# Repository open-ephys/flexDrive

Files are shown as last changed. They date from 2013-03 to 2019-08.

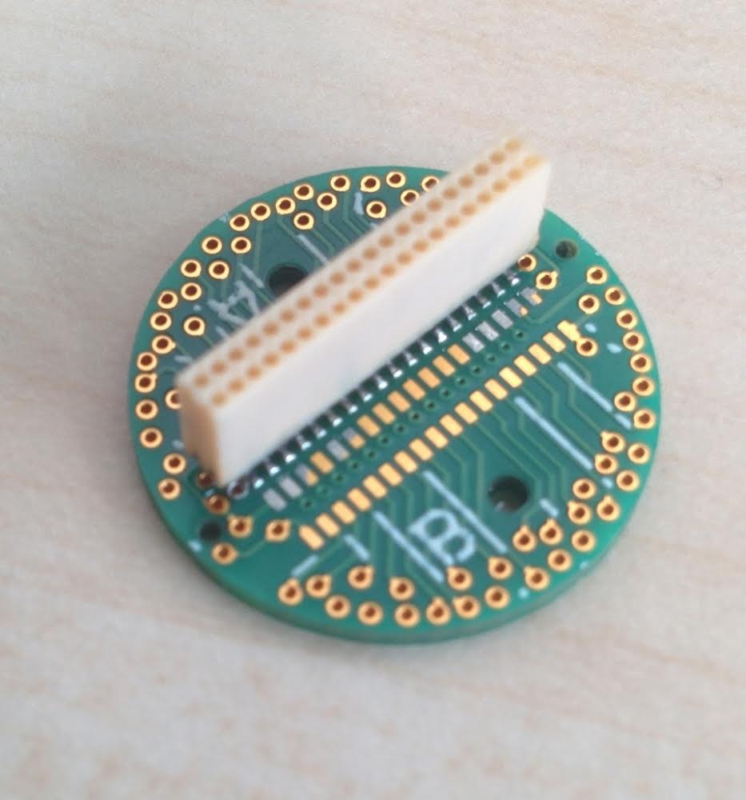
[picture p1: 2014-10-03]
Electrode Interface Boards/Omnetics 2x32/aligned connectors/doc/2x32aligned_eib_half_soldered.jpg

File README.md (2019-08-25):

flexDrive
==========

__This design is deprecated, we recommend switching to the newer Open Ephys shuttle drive__ (preprint: https://www.biorxiv.org/content/10.1101/746651v1), (git repository: https://github.com/open-ephys/shuttle-drive). This new design is superior to the flexDrive in all aspects (robustness, travel distance, build speed), and we strongly recommend switching.

The flexDrive is a compact hyperdrive for up to 16 independently movable electrodes. It uses a novel spring mechanism to adjust electrode depth.

This repository only contains design files. See https://open-ephys.atlassian.net/wiki/display/OEW/flexDrive for documentation and assembly instructions.

File types
------------
- .brd = EAGLE board files; describe the physical layout of the printed circuit board
- .md = Markdown files; most likely a README file; can be viewed with any text edtior
- .txt  = standard text files
- "gerber" files (.top, .bsk, .oln, etc.) = contain machine-readable instructions for creating the printed circuit board; these are sent to a fab house (such as Sunstone Circuits) for PCB production
- .SLDPRT files = SolidWorks part files; contain CAD models of 3D components
- .SLDDRW files = SolidWorks drawing files; contain 2D images of components
- .DXF = another type of 2D drawing file that can be opened in Adobe Illustrator or similar software
- .STL files = stereolithography files; can be sent to a rapid prototyping service (such as Shapeways) to create 3D objects
- .pdf files = standard document format for viewing and editing 2D images

Paper
----------

Voigts J, Siegle JH, Pritchett DL and Moore CI (2013). 
The flexDrive: An ultra-light implant for optical control and highly parallel chronic recording of neuronal ensembles in freely moving mice. 
Front. Syst. Neurosci. 7:8. doi: 10.3389/fnsys.2013.00008

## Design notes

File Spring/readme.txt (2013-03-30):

The flexDrive is an implant for chronic extracellular electrophysiology.
The design of the flexDrive is released under the The TAPR Open Hardware License
Get the latest revision of the design source files at http://github.com/open-ephys/flexDrive

The spring design files in this repository are designed for use with wire EDM with a kerf width of 13mil, using any other process requires adapting at least the screw opening in the spring. 

Editing the sldprt of DXF files requires Dassault Systems Solidworks (http://www.solidworks.com/)

Voigts J, Siegle JH, Pritchett DL and Moore CI (2013). 
The flexDrive: An ultra-light implant for optical control and highly parallel chronic recording of neuronal ensembles in freely moving mice. 
Front. Syst. Neurosci. 7:8. doi: 10.3389/fnsys.2013.00008

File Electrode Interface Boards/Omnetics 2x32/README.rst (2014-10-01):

2x Omnetics 36-channel "nano-strip" connectors, 4 guide posts
---------------------------------------------------------------------------------

The 64ch_eib_omnetics_3fibers Electrode Interface Board  (EIB) is designed to form a connection between 64 microwire electrodes or individual wires forming stereotrodes or tetrodes, and two 32 channel omnetics connectors.

The 'offset variant' provides more space between the two omnetics connectors and can be soldered by hand if needed, but won't fit the 64 channel headstage.

The aligned variant fits the 64 channel headstage, and can also be used with 2x 32 channel headstages, if they're aligned with the PCB facing away from the center (this will affect the channel mapping).

See the documentation on https://open-ephys.atlassian.net/wiki/display/OEW/flexDrive for building and use instructions.

**WARNING:** These designs will not work if fabricated as 'standard quality' PCB, see Fabrication instructions and get in touch with your PCB maker before placing orders!

Connectors on EIB:
~~~~~~~~~~~~~~~

* male surface-mount vertical (A79026-001 / NPD-36-VV-GS)

Connectors on Headstage:
~~~~~~~~~~~~~~~~~~
 
* female surface-mount horizontal (A79025-001 / NSD-36-AA-GS)
* female surface-mount vertical (A79027-001 / NSD-36-VV-GS)

Pin mapping:
~~~~~~~~~~~~~~~~~~
The pin mapping for the GROUND and REFERENCE channels on the offset connector EIB are compatible with the mapping on the Intan evaluation system headstages (http://www.intantech.com/files/Intan_RHD2000_eval_system.pdf) and the open-ephys headstages (open-ephys.org)

(viewed down onto the eib, looking onto the bottom of the headstage connector this would be flipped)

| ref  | ch | ch | ... | ch | gnd |
| gnd | ch | ch | ... | ch | ref |

For channel mappings of individual EIB designs, look at the documenttaiopn in that EIBs folder. Orientation of headstages affects the channel mapping - when in doubt you should sanity check your mapping by connecting a EIB to your system and grounding out or injecting a signal on individual vias.

Hole sizes:
~~~~~~~~~~~~~~~~~~

The hole size on this EIB (0.3mm) is suited for use with SMALL neuralynx gold pins (http://neuralynx.com/products/electrode_interface_boards/eib_pins) 

The three mounting holes for optical fiber ferrules are sized for use with 1.25mm OD ferrules.

See the documentation on https://open-ephys.atlassian.net/wiki/display/OEW/flexDrive for building and use instructions.

Fabrication instructions:
~~~~~~~~~~~~~~~~~~

These EIBs can be fabricated with the following process
- 5mil trace with / 5mil trace space
- gold immersion finish
- 0.03 inch board thickness (not critical, can be made thicker)
- top silkscreen

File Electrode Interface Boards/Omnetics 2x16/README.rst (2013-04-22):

Omnetics 18-channel "nano-strip" connectors, 4 guide posts
---------------------------------------------------------------------------------

The 32ch_eib_omnetics_2fibers and 32ch_eib_omnetics_1fiber Electrode Interface Boards (EIB) aredesigned to form a connection between 32microwire electrodes or individual wires forming stereotrodes or tetrodes, and two 16 channel omnetics connectors.

See the documentation on http://github.com/open-ephys/flexDrive for building and use instructions.

Connectors on EIB:
~~~~~~~~~~~~~~~

* male surface-mount vertical (A79042-001 / NPD-18-VV-GS)

Connectors on Headstage:
~~~~~~~~~~~~~~~~~~
 
* female surface mount horizontal (A79041-001 / NSD-18-AA-GS)
* female surface mount vertical (A79043-001 / NSD-18-VV-GS)

Pin mapping:
~~~~~~~~~~~~~~~~~~
The pin mapping for the GROUND and REFERENCE channels on this EIB are compatible with the mapping on the standard omnetics 16 channel headstages.

Hole sizes:
~~~~~~~~~~~~~~~~~~
The hole size on this EIB (0.5mm) is suited for use with LARGE neuralynx gold pins (http://neuralynx.com/products/electrode_interface_boards/eib_pins) 

The mounting holes for optical fiber ferrules are sized for use with 1.25mm OD ferrules.

Fabrication instructions:
~~~~~~~~~~~~~~~~~~

This EIB can be fabricated with the following process
- 8mil trace with / 8mil trace space
- 0.03 inch board thickness (not critical, can be made thicker)
- top silkscreen

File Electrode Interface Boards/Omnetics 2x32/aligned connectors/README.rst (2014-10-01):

2x Omnetics 36-channel "nano-strip" connectors, 4 guide posts
---------------------------------------------------------------------------------

Fabrication instructions:
~~~~~~~~~~~~~~~~~~

check if these are correct:

These EIBs can be fabricated with the following process
- 5mil trace with / 5mil trace space
- gold immersion finish
- 0.03 inch board thickness (not critical, can be made thicker)
- top silkscreen

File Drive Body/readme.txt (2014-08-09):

The flexDrive is an implant for chronic extracellular electrophysiology.
The design of the flexDrive is released under the The TAPR Open Hardware License
Get the latest revision of the design source files at http://github.com/open-ephys/flexDrive

folder for_small_eibs holds the standard design that works with the 32ch eib and 64ch eib (small gold pins)

folder for_larger_64ch_eib contains a variant for use with the bigger 64ch eib (large gold pins)

Editing the sldprt files requires Dassault Systems Solidworks (http://www.solidworks.com/)

We also provide a STL file for use with 3d-printing software or services.

See (http://open-ephys.github.io/flexDrive/custom_parts.html) for ordering info.

Voigts J, Siegle JH, Pritchett DL and Moore CI (2013). 
The flexDrive: An ultra-light implant for optical control and highly parallel chronic recording of neuronal ensembles in freely moving mice. 
Front. Syst. Neurosci. 7:8. doi: 10.3389/fnsys.2013.00008

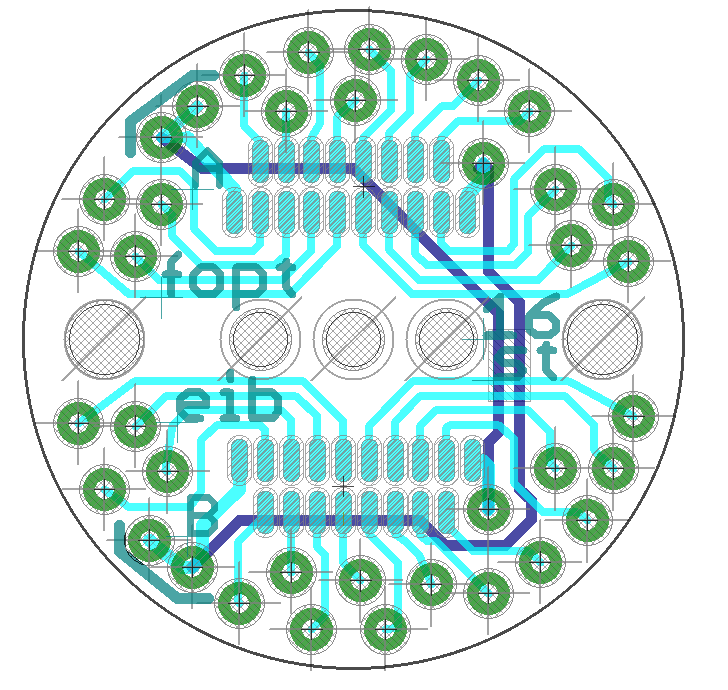
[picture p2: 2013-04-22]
Electrode Interface Boards/Omnetics 2x16/3 fiber optics/Open Ephys EIB Omnetics 2x16 3 fibers.png

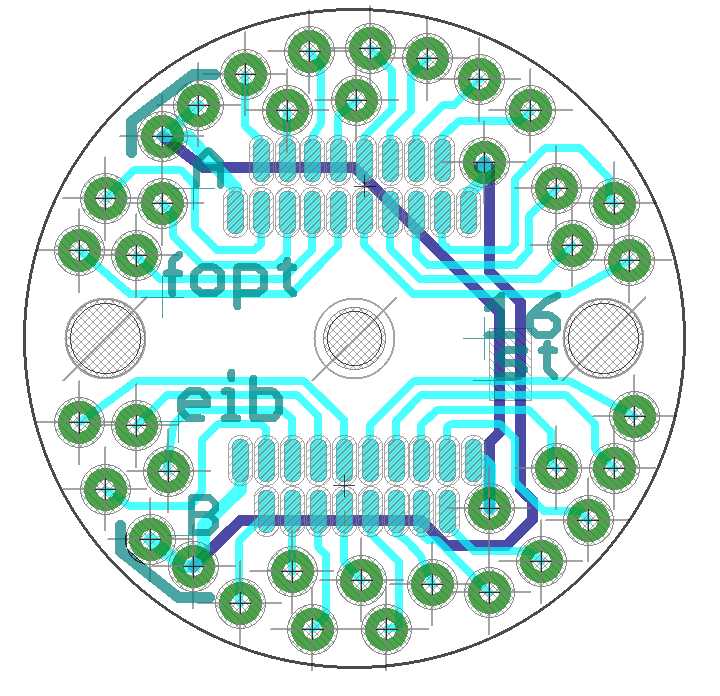
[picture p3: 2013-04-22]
Electrode Interface Boards/Omnetics 2x16/1 fiber optic/Open Ephys EIB Omnetics 2x16 1 fiber.png

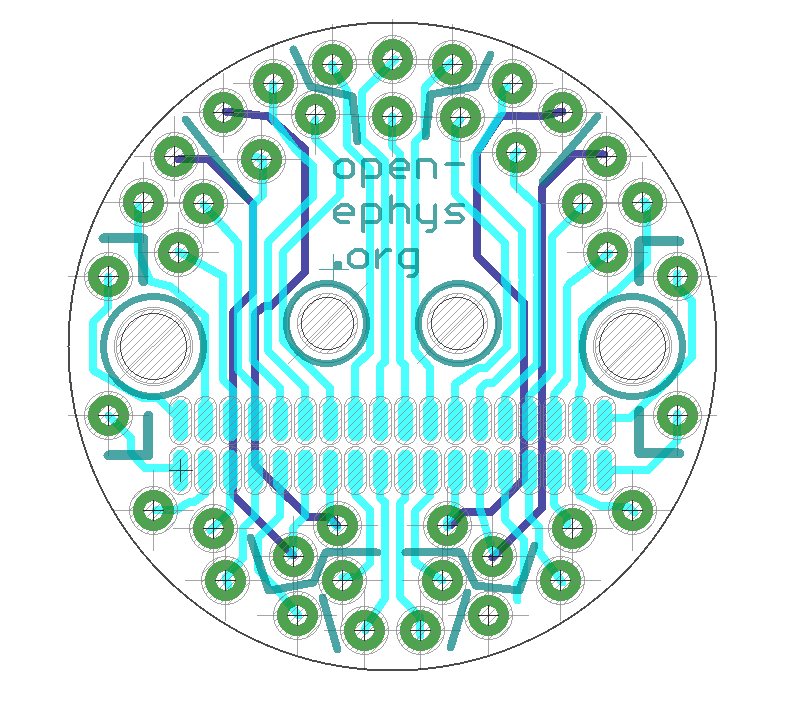
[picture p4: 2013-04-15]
Electrode Interface Boards/Omnetics 1x32/2 fibers/Open Ephys EIB Omnetics 1x32 2 fibers.png

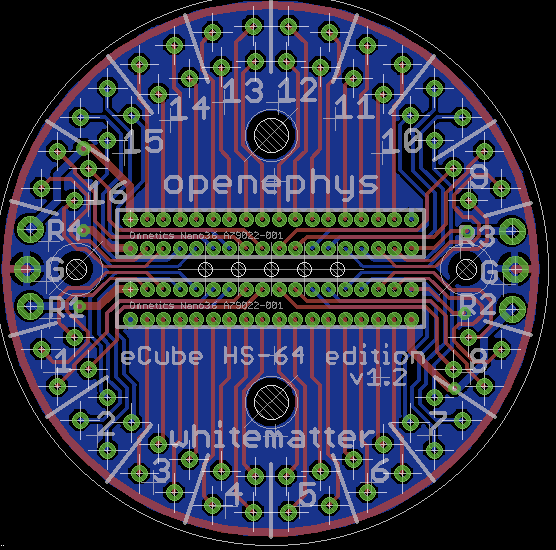
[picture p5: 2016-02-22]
Electrode Interface Boards/eCube HS-64/ecube EIB HS64 2xOmnetics r1 0.30mm.tiff

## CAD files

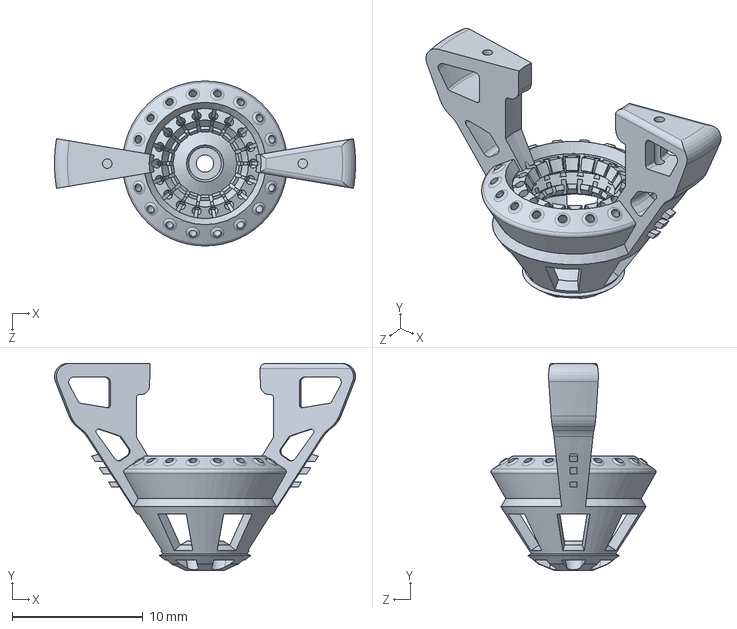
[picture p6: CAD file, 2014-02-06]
Drive Body/for_larger_64ch_eib/flexDrive_single_hole_16drives_rev1.2.SLDPRT
23.1 x 15.9 x 12.6 mm

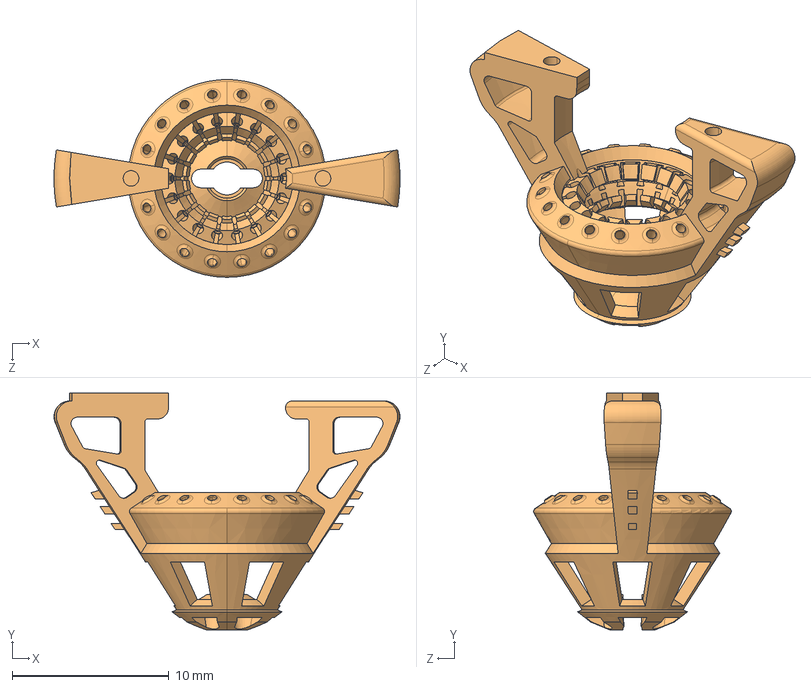
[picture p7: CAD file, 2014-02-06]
Drive Body/for_small_eibs/flexDrive_base_16drives_rev1.1.STEP
22.1 x 15.1 x 12.6 mm

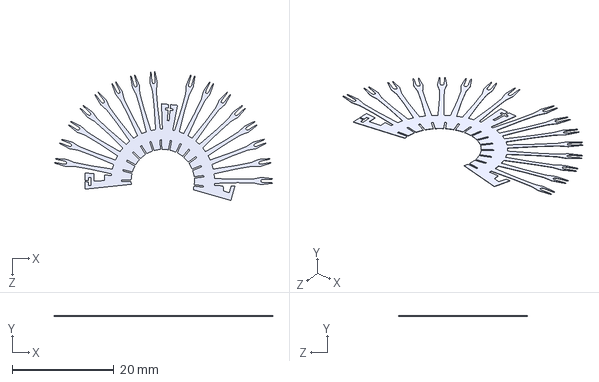
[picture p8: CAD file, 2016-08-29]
Spring/flexDrive_spring_16drives_rev1.2_nokerf.STEP
42.8 x 0.05 x 25.3 mm

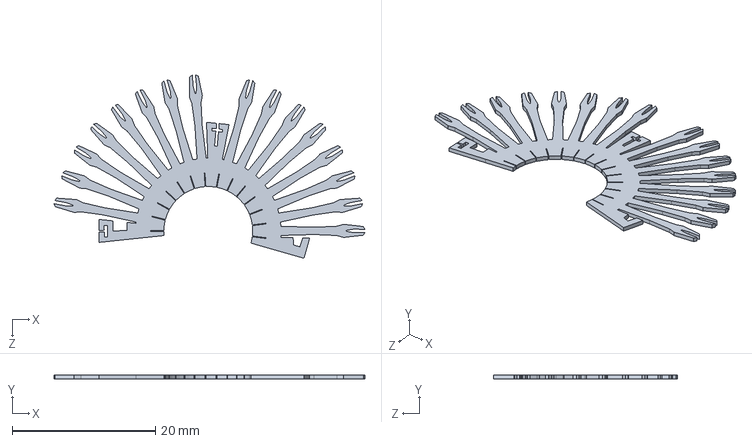
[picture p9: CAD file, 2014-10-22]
Spring/flexDrive_spring_16drives_rev1.2_for_13mil_kerf.SLDPRT
43.4 x 0.5 x 25.6 mm

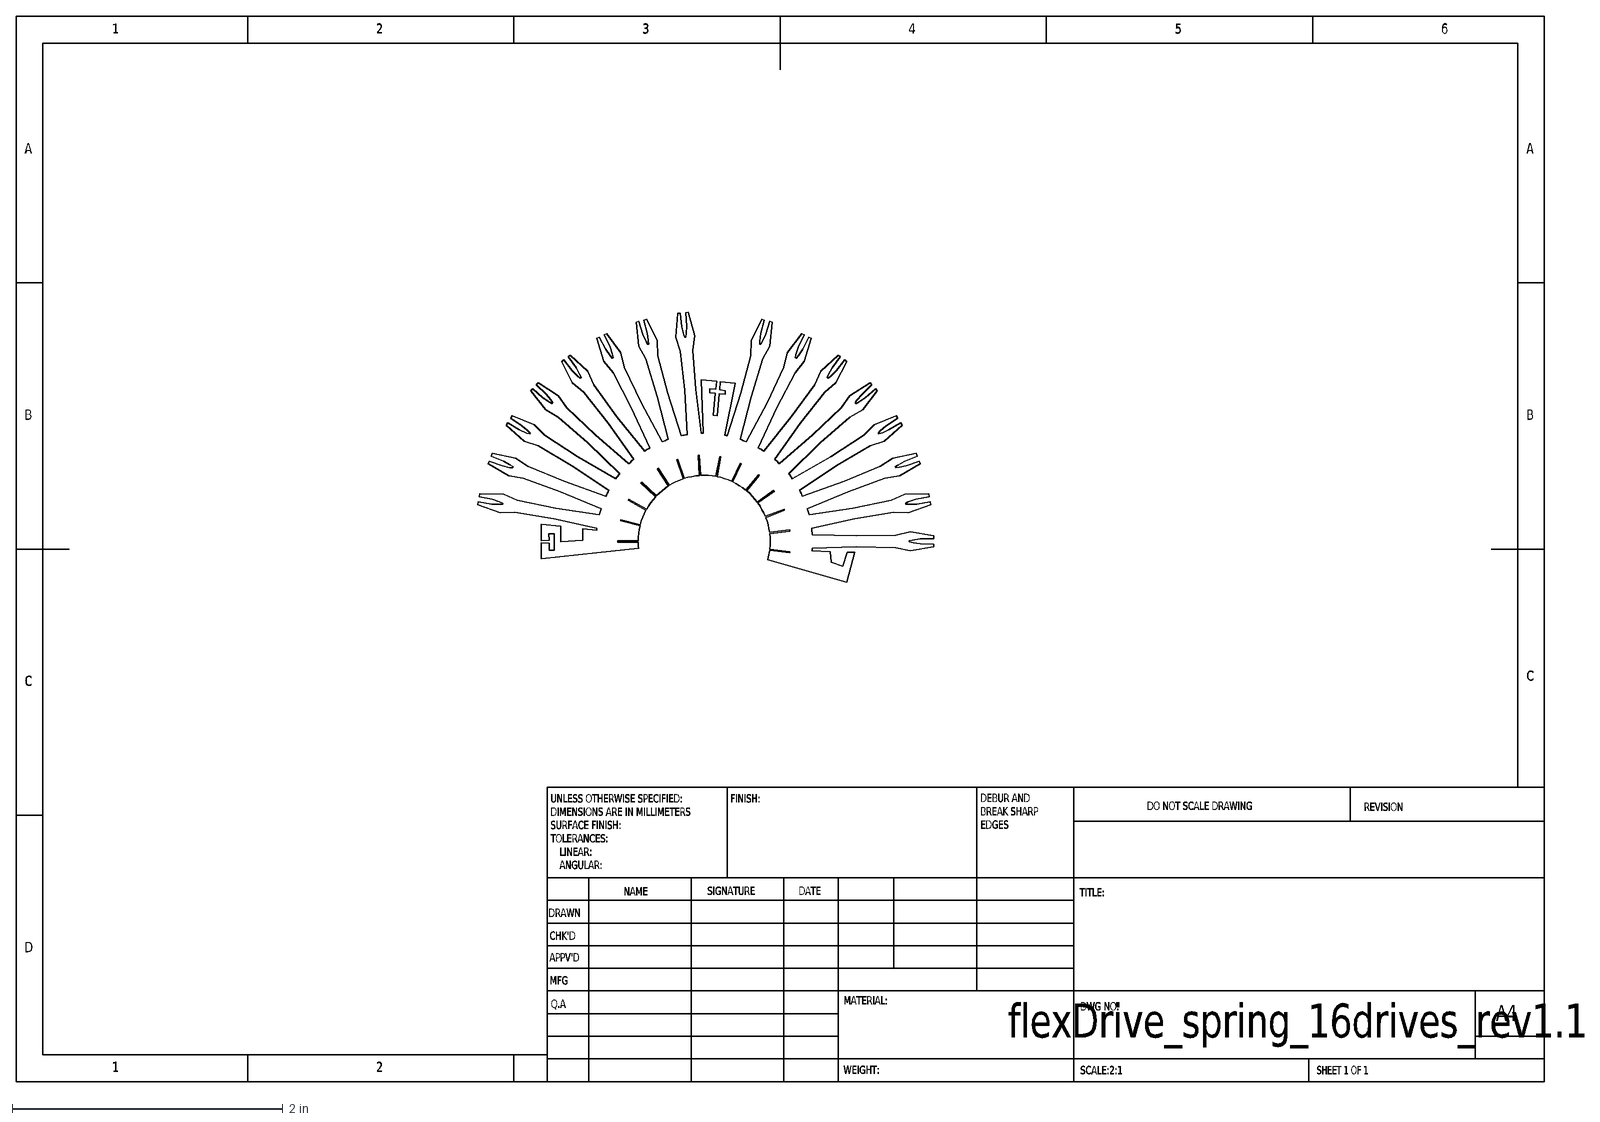
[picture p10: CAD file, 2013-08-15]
Spring/flexDrive_spring_16drives_rev1.1_wireedm_dfx_inch.DXF
B
C
D
1
2
A
3
4
5
6
DRAWN
CHK'D
APPV'D
MFG
Q.A
UNLESS OTHERWISE SPECIFIED:
DIMENSIONS ARE IN MILLIMETERS
SURFACE FINISH:
TOLERANCES:
LINEAR:
ANGULAR:
FINISH:
DEBUR AND
BREAK SHARP
EDGES
NAME
SIGNATURE
DATE
MATERIAL:
DO NOT SCALE DRAWING
REVISION
TITLE:
DWG NO.
SCALE:2:1
SHEET 1 OF 1
A4
WEIGHT:
flexDrive_spring_16drives_rev1.1

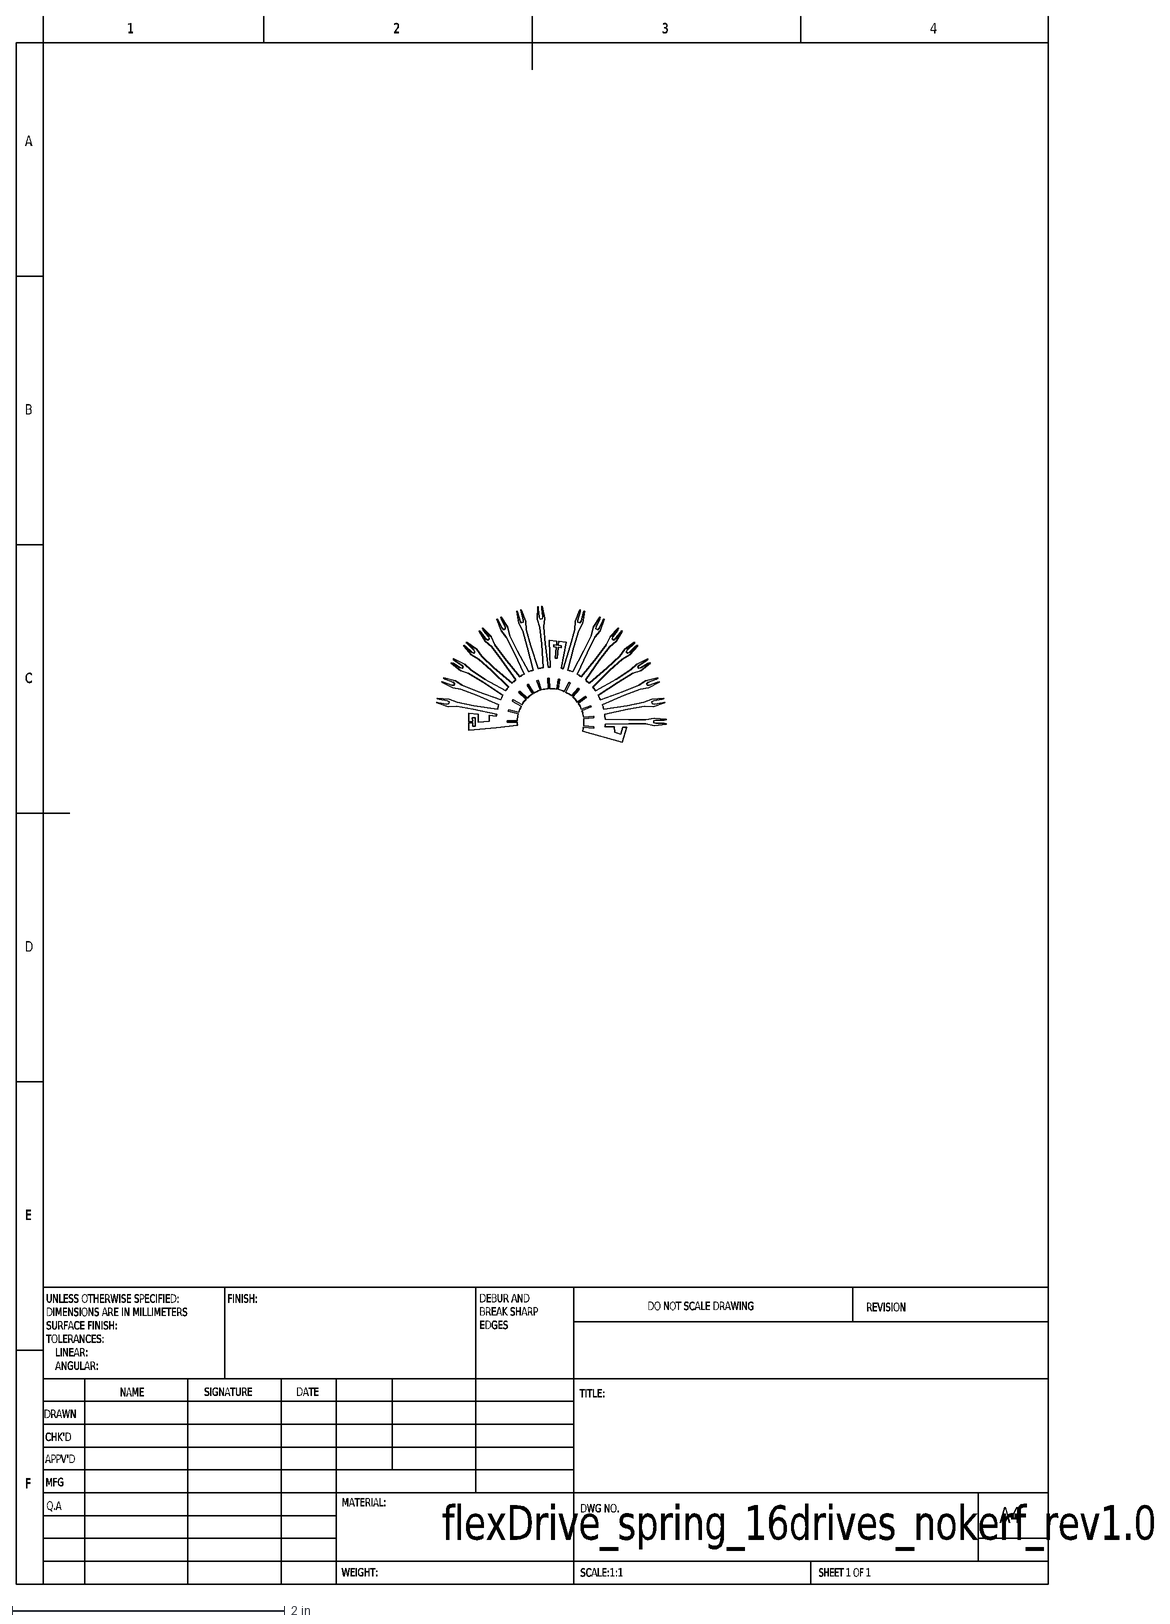
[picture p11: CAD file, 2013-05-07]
Spring/flexDrive_spring_16drives_nokerf_rev1.0_wireedm_dfx_inch.DXF
C
2
3
1
4
B
A
D
E
F
flexDrive_spring_16drives_nokerf_rev1.0
WEIGHT:
A4
SHEET 1 OF 1
SCALE:1:1
DWG NO.
TITLE:
REVISION
DO NOT SCALE DRAWING
MATERIAL:
DATE
SIGNATURE
NAME
DEBUR AND
BREAK SHARP
EDGES
FINISH:
UNLESS OTHERWISE SPECIFIED:
DIMENSIONS ARE IN MILLIMETERS
SURFACE FINISH:
TOLERANCES:
LINEAR:
ANGULAR:
Q.A
MFG
APPV'D
CHK'D
DRAWN

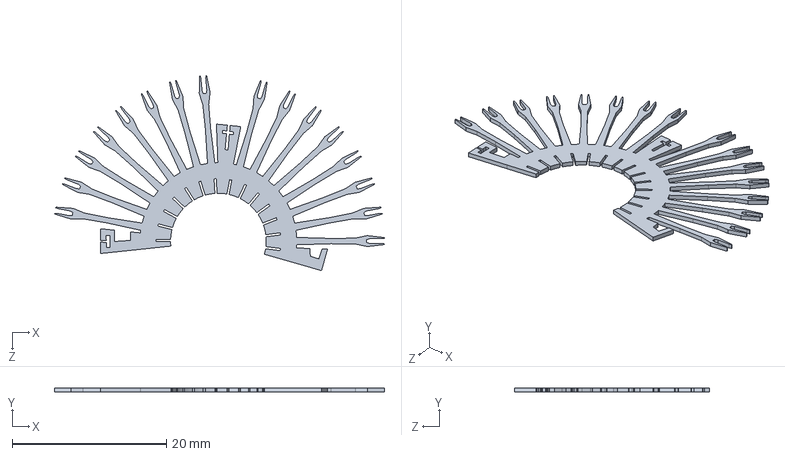
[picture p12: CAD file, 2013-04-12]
Spring/flexDrive_spring_16drives_nokerf_rev1.0.SLDPRT
42.8 x 0.5 x 25.3 mm

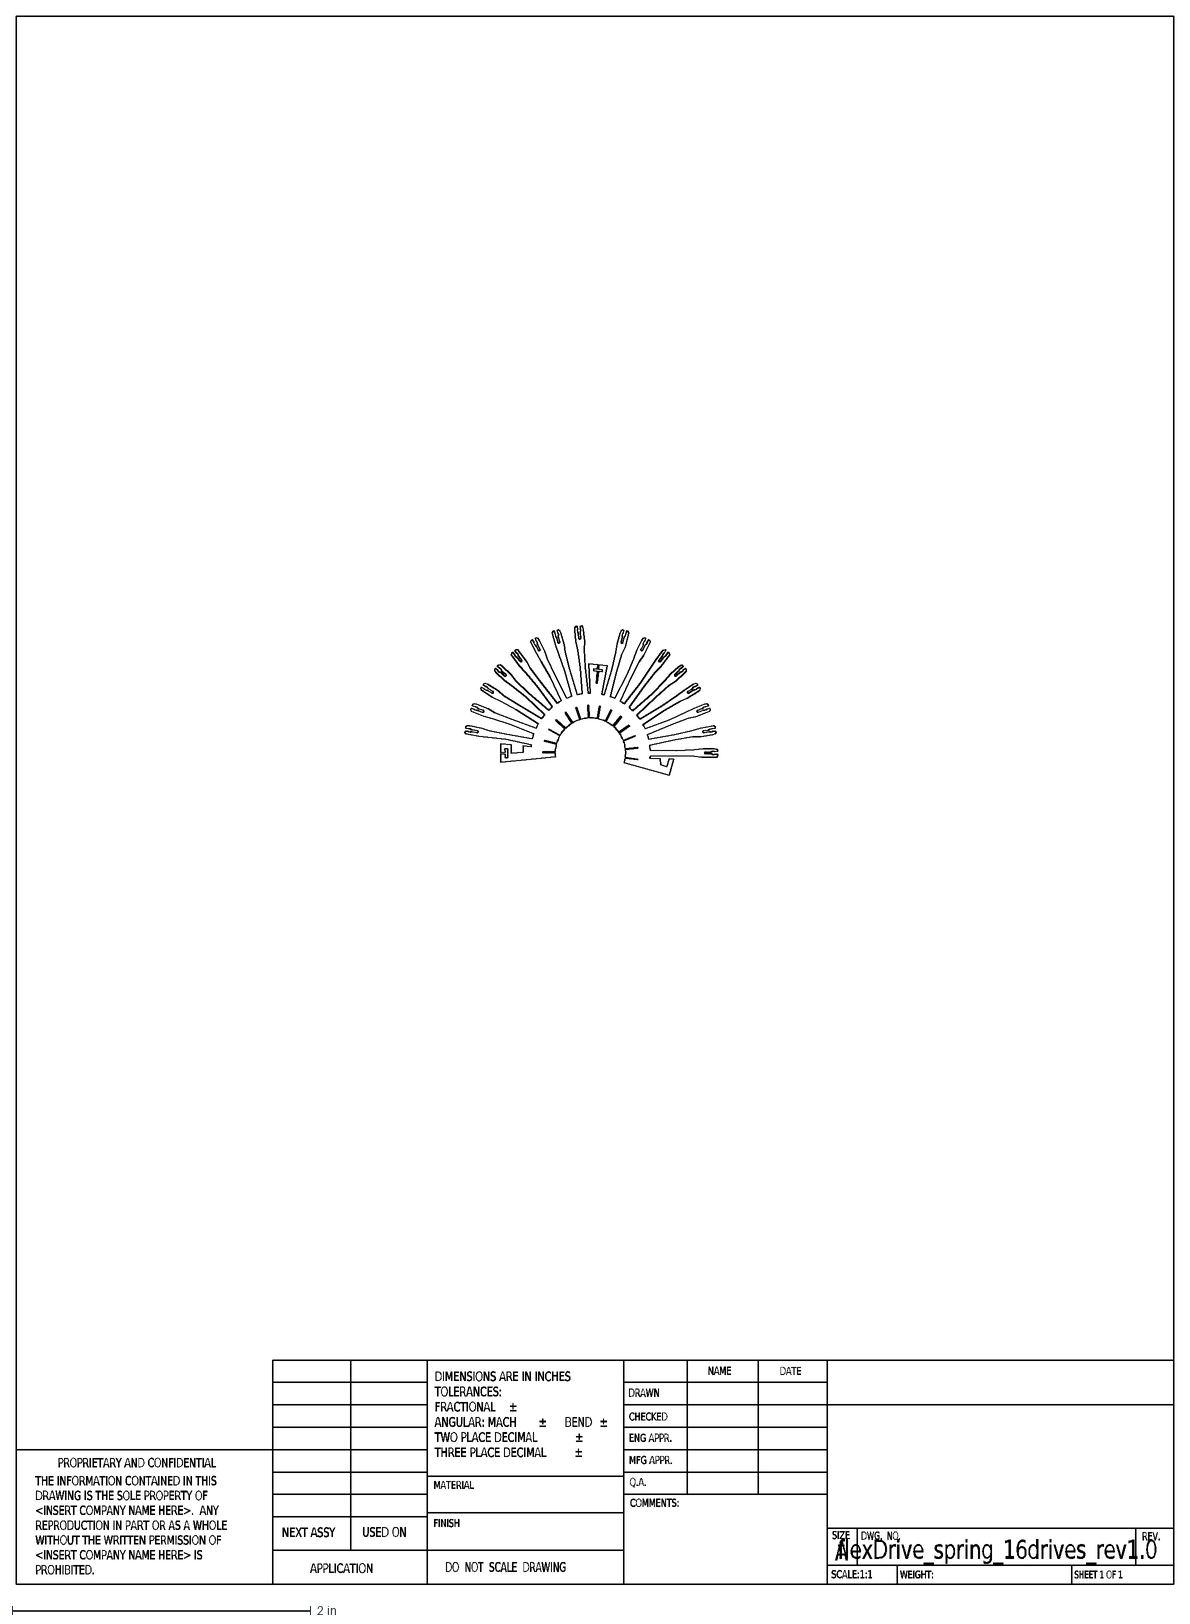
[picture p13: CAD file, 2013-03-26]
Spring/flexDrive_spring_16drives_rev1.0_wireedm_dfx_mm.DXF
WEIGHT:
flexDrive_spring_16drives_rev1.0
PROPRIETARY AND CONFIDENTIAL
THE INFORMATION CONTAINED IN THIS
DRAWING IS THE SOLE PROPERTY OF
<INSERT COMPANY NAME HERE>. ANY
REPRODUCTION IN PART OR AS A WHOLE
WITHOUT THE WRITTEN PERMISSION OF
<INSERT COMPANY NAME HERE> IS
PROHIBITED.
COMMENTS:
SHEET 1 OF 1
Q.A.
MFG APPR.
ENG APPR.
CHECKED
DRAWN
DATE
NAME
DIMENSIONS ARE IN INCHES
TOLERANCES:
FRACTIONAL
±
ANGULAR: MACH
BEND
TWO PLACE DECIMAL
THREE PLACE DECIMAL
NEXT ASSY
USED ON
APPLICATION
DO NOT SCALE DRAWING
FINISH
MATERIAL
REV.
A
DWG. NO.
SIZE
SCALE:1:1

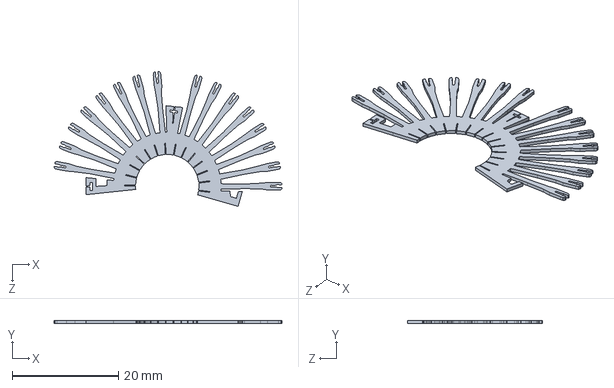
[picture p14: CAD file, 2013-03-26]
Spring/flexDrive_spring_16drives_rev1.0.SLDPRT
43.0 x 0.5 x 25.4 mm

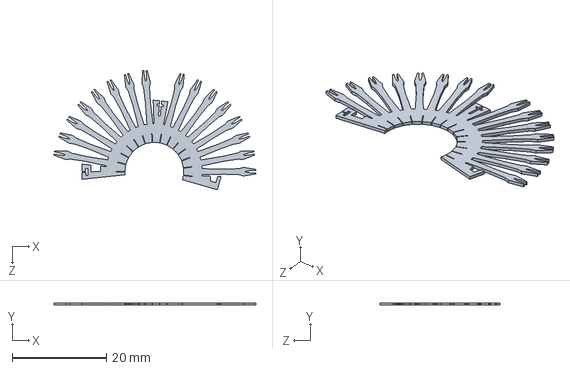
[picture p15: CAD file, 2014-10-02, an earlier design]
Spring/flexDrive_spring_16drives_rev1.1_for_13mil_kerf.SLDPRT
42.8 x 0.5 x 25.3 mm

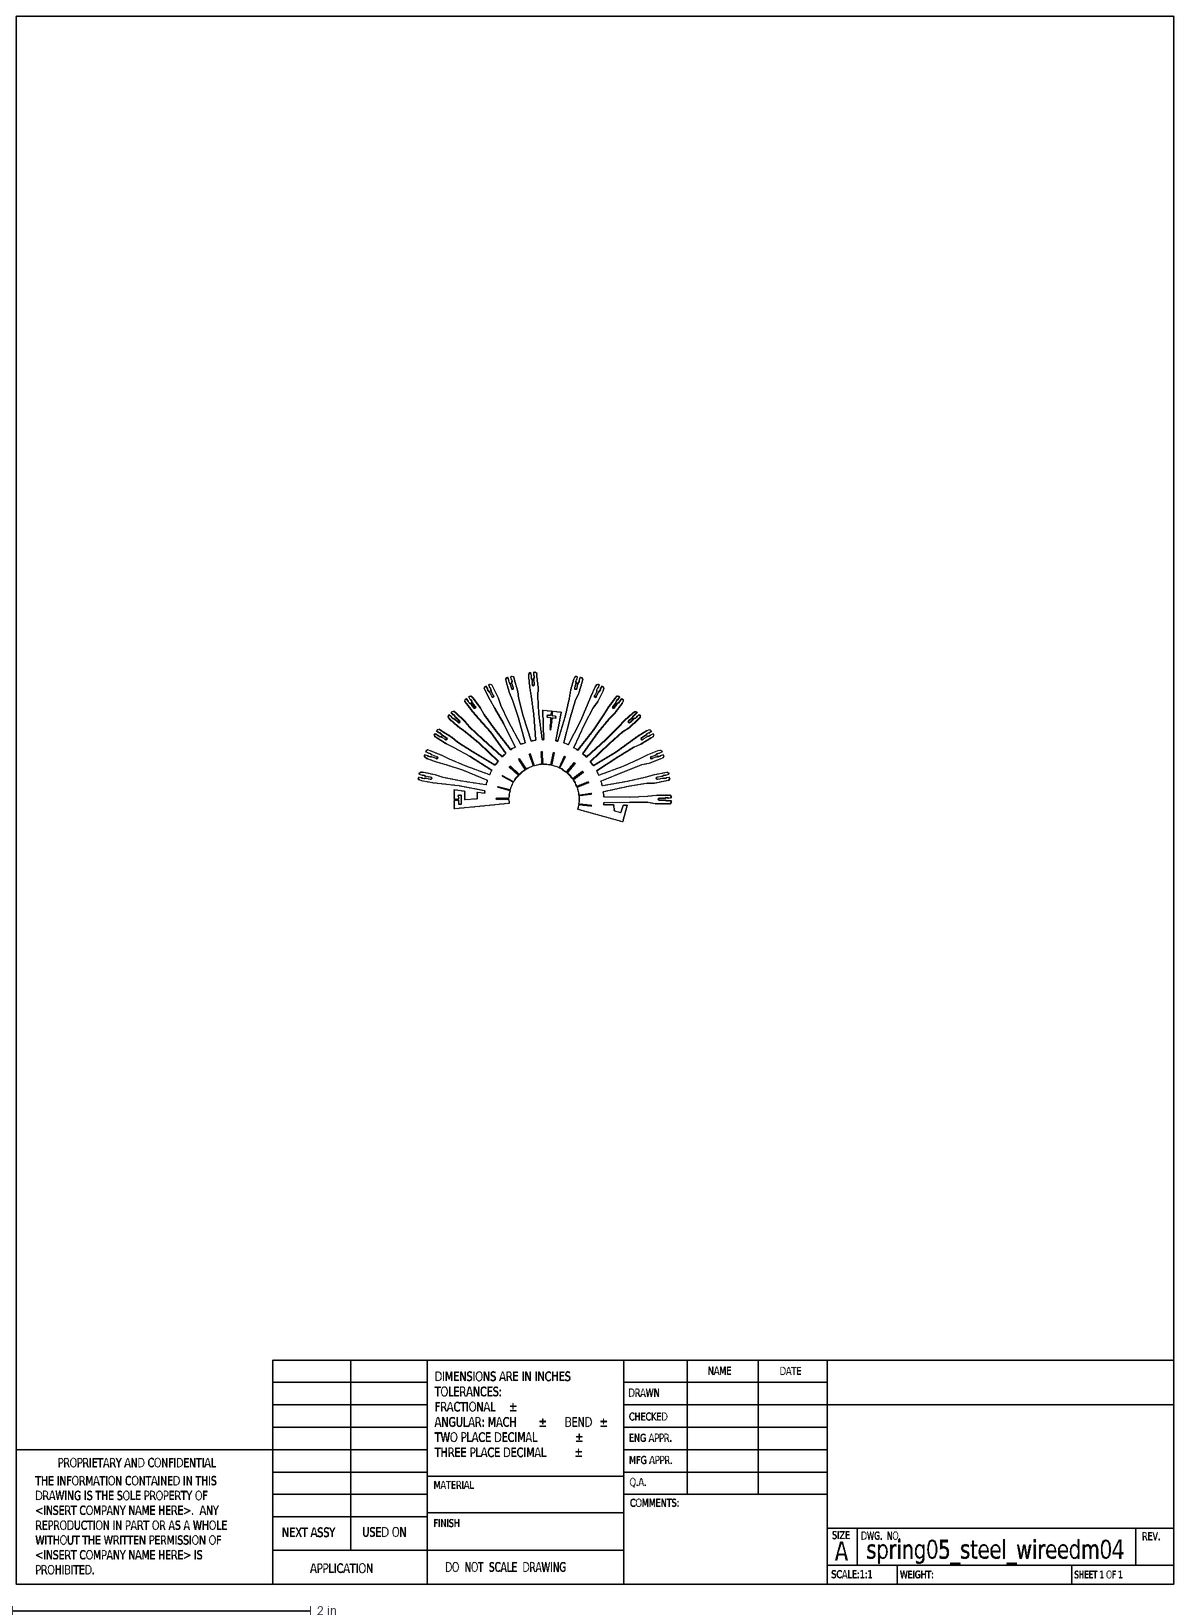
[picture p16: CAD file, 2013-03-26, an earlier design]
Spring/flexDrive_spring_16drives_rev1.0_wireedm_dfx_inch.DXF
WEIGHT:
spring05_steel_wireedm04
PROPRIETARY AND CONFIDENTIAL
THE INFORMATION CONTAINED IN THIS
DRAWING IS THE SOLE PROPERTY OF
<INSERT COMPANY NAME HERE>. ANY
REPRODUCTION IN PART OR AS A WHOLE
WITHOUT THE WRITTEN PERMISSION OF
<INSERT COMPANY NAME HERE> IS
PROHIBITED.
COMMENTS:
SHEET 1 OF 1
Q.A.
MFG APPR.
ENG APPR.
CHECKED
DRAWN
DATE
NAME
DIMENSIONS ARE IN INCHES
TOLERANCES:
FRACTIONAL
±
ANGULAR: MACH
BEND
TWO PLACE DECIMAL
THREE PLACE DECIMAL
NEXT ASSY
USED ON
APPLICATION
DO NOT SCALE DRAWING
FINISH
MATERIAL
REV.
A
DWG. NO.
SIZE
SCALE:1:1

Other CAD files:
Drive Body/for_larger_64ch_eib/flexDrive_ca1_bilateral_16drives_rev1.2.SLDPRT
Drive Body/for_small_eibs/flexDrive_ca1_bilateral_16drives_rev1.1.STEP
Drive Body/for_small_eibs/flexDrive_base_16drives_rev1.0.SLDPRT
Drive Body/for_larger_64ch_eib/flexDrive_ca1_bilateral_16drives_rev1.2.STL
Drive Body/for_larger_64ch_eib/flexDrive_single_hole_16drives_rev1.2.STL
Drive Body/for_small_eibs/flexDrive_base_16drives_rev1.1.SLDDRW
Drive Body/for_small_eibs/flexDrive_base_16drives_rev1.1.SLDPRT
Drive Body/for_small_eibs/flexDrive_base_16drives_rev1.1.STL
Drive Body/for_small_eibs/flexDrive_ca1_bilateral_16drives_rev1.1.SLDPRT
Drive Body/for_small_eibs/flexDrive_ca1_bilateral_16drives_rev1.1.STL
Drive Body/for_small_eibs/flexDrive_spring_16drives_rev1.1.SLDDRW
Spring/flexDrive_spring_16drives_rev1.0.SLDDRW
Spring/flexDrive_spring_16drives_rev1.1_for_13mil_kerf.DXF
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

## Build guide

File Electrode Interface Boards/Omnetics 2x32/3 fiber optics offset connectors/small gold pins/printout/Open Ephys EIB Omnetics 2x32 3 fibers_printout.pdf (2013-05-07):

Date:
Drive id:
Mouse id:

Fiber

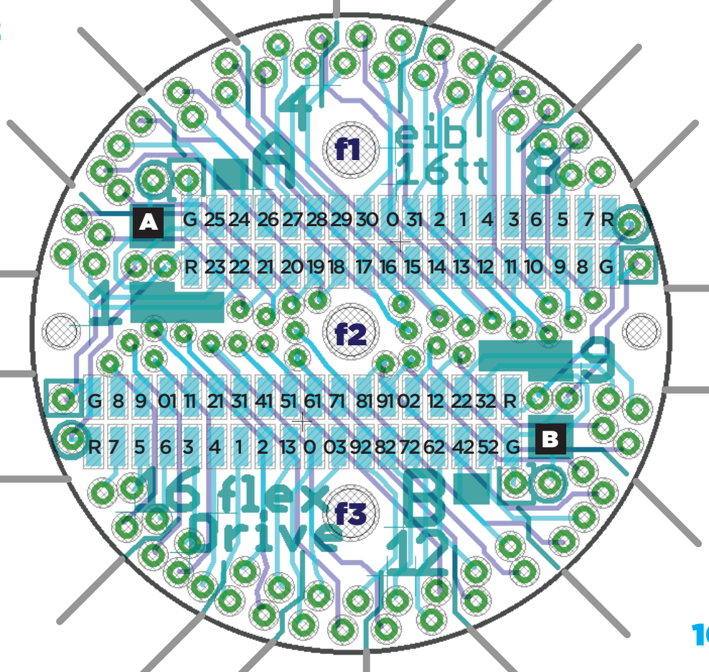
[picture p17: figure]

connections

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
13 12

14

15

16

gnd/ref

gnd/ref

9

:
:
:

G 25 24 26 27 28 29 30 0 31 2 1 4 3 6 5 7 R

R 23 22 21 20 19 18 17 16 15 14 13 12 11 10 9 8 G

G 25 24 26 27 28 29 30 0 31 2 1 4 3 6 5 7 R

R 23 22 21 20 19 18 17 16 15 14 13 12 11 10 9 8 G

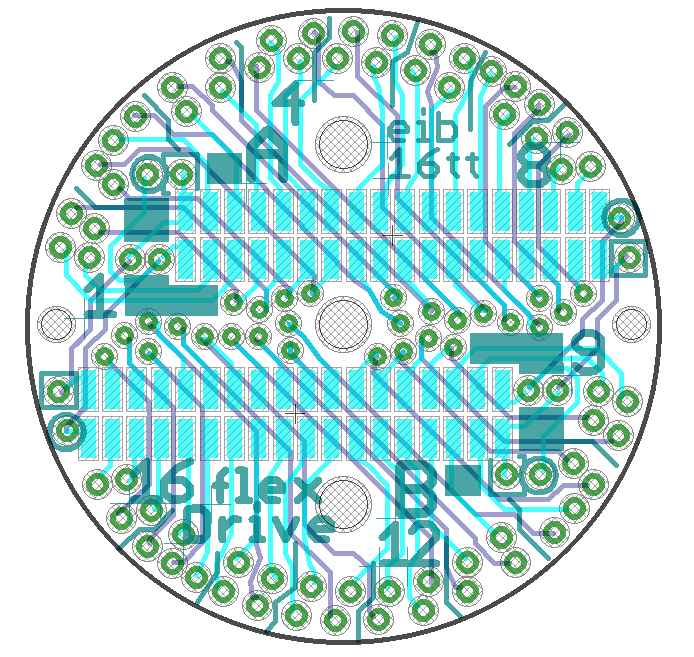
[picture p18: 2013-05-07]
Electrode Interface Boards/Omnetics 2x32/3 fiber optics offset connectors/small gold pins/printout/Open Ephys EIB Omnetics 2x32 3 fibers light_colors.png

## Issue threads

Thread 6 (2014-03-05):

Microdrives getting stuck during adjusting

jvoigts, 2014-03-05:
Microdrives are sometimes getting stuck during adjusting.

jvoigts, 2016-01-06:
If the shuttle tubes are too long and extend into the curved section of the guide tubes when lowered this will increase friction and could also lead to sticking. See https://open-ephys.atlassian.net/wiki/display/OEW/4+-+Assembling+the+drive+body for details.

Closed 2017-02-27.

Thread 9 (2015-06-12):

Gold pins keep falling out

jvoigts, 2015-06-12:
Gold pins sometimes fall out over the lifetime of a drive unless they're secured.
The best way to ensure they stay in is to just epoxy them to the EIB after gold plating.
See here for details: https://open-ephys.atlassian.net/wiki/display/OEW/6+-+Shielding+the+drive

jvoigts, 2017-04-19:
For re-using the EIBs afterwards, just dump them into ~70% ethanol for a few days. This softens the epoxy so it can be removed easily. Carefully pull out epoxy from under the omnetics connectors as well, and re-glue them. Gold pins should likely not be re-used. This method works with omnetics connectors because their material is not affected by ethanol, but might destroy other types of connectors.

Closed 2015-06-12.

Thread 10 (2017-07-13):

Etching Mask

AGenews, 2017-07-13:
Hi,
I plan to play a little bit and find a way to etch those springs. Unfortunately I am bound to Linux and Freecad refuses to open any of the provided files properly. So could you upload a *.SVG* or even a KiCAD file with the outlines of the spring?
Thanks + Best,
Andreas

jvoigts, 2017-07-13:
Hi, just re-exported this as DXF DWG and PDF ( dea8cec32c9d1df16cb5ae3bcf781cfb7e4ea197 ), i think that's the closest i can get with solidworks here. That said, if you have a few months to spare before you need the drives, maybe hold off on this. I might have an updated design ready then that does not require a spring at all.

AGenews, 2017-07-14:
Thanks a lot!

Closed 2017-07-14.

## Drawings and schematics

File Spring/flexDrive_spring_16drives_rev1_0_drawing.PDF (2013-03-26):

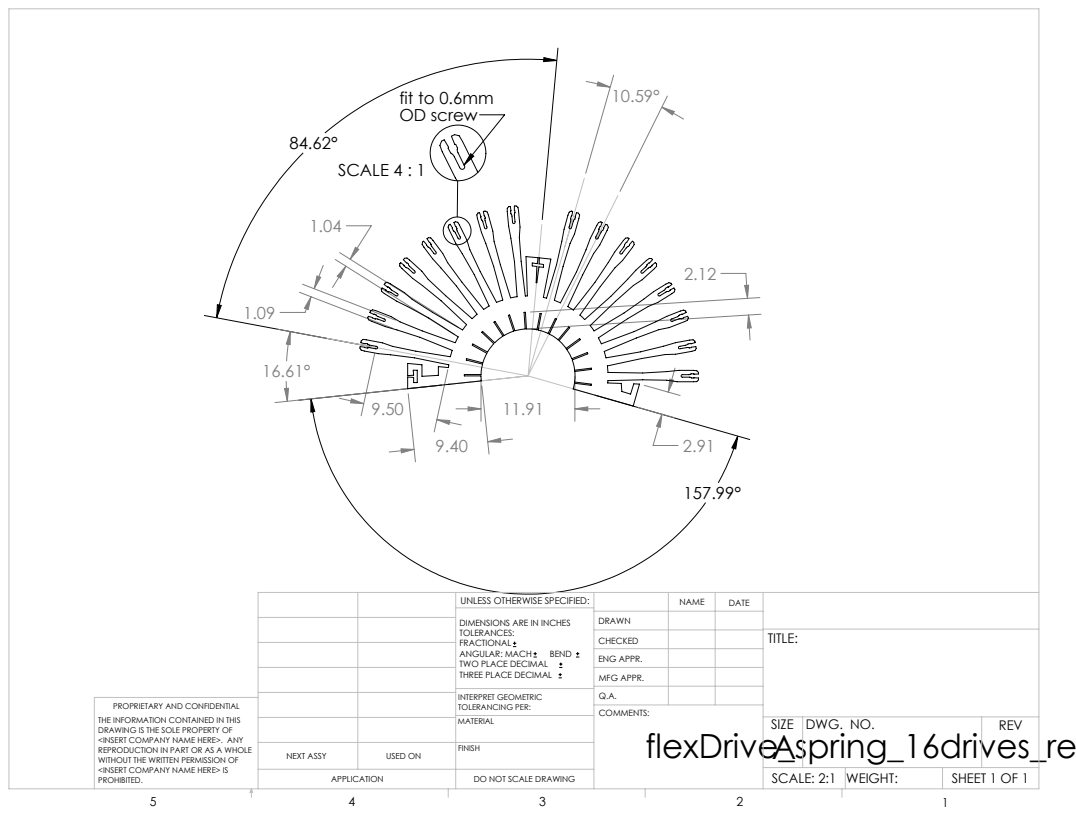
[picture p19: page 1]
SCALE 4 : 1; fit to 0.6mm OD screw; SHEET 1 OF 1; SCALE: 2:1 WEIGHT:; DWG. NO.; REV; MFG APPR.; ENG APPR.; INTERPRET GEOMETRIC TOLERANCING PER:; ANGULAR: MACH; BEND; NEXT ASSY; USED ON

UNLESS OTHERWISE SPECIFIED:

DIMENSIONS ARE IN INCHES
TOLERANCES:
FRACTIONAL
TWO PLACE DECIMAL
THREE PLACE DECIMAL

PROPRIETARY AND CONFIDENTIAL
THE INFORMATION CONTAINED IN THIS
DRAWING IS THE SOLE PROPERTY OF
<INSERT COMPANY NAME HERE>. ANY
REPRODUCTION IN PART OR AS A WHOLE
WITHOUT THE WRITTEN PERMISSION OF
<INSERT COMPANY NAME HERE> IS
PROHIBITED.

DO NOT SCALE DRAWING

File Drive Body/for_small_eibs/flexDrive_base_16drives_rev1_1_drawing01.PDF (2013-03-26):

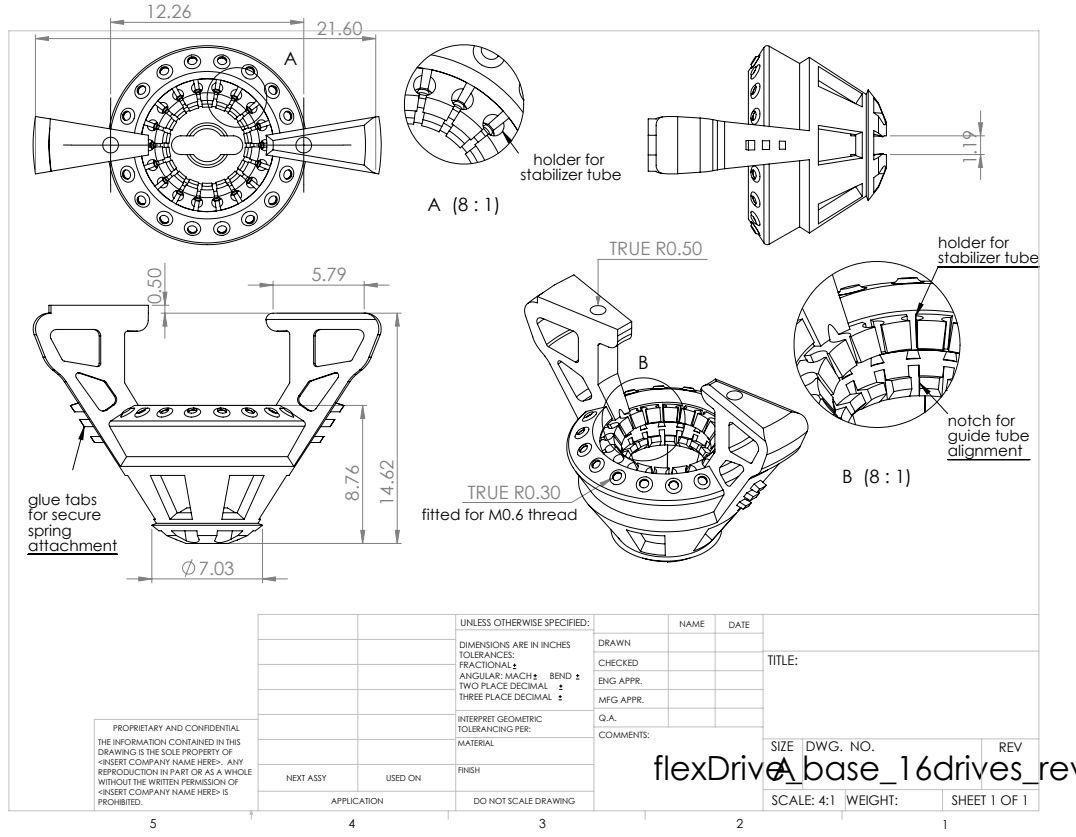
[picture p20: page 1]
TRUE R0.50; glue tabs for secure; holder for stabilizer tube; notch for guide tube; SHEET 1 OF 1; SCALE: 4:1 WEIGHT:; DWG. NO.; REV; MFG APPR.; ENG APPR.; INTERPRET GEOMETRIC TOLERANCING PER:; ANGULAR: MACH; BEND; NEXT ASSY; USED ON

TRUE R0.30
fitted for M0.6 thread

UNLESS OTHERWISE SPECIFIED:

DIMENSIONS ARE IN INCHES
TOLERANCES:
FRACTIONAL
TWO PLACE DECIMAL
THREE PLACE DECIMAL

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

DO NOT SCALE DRAWING

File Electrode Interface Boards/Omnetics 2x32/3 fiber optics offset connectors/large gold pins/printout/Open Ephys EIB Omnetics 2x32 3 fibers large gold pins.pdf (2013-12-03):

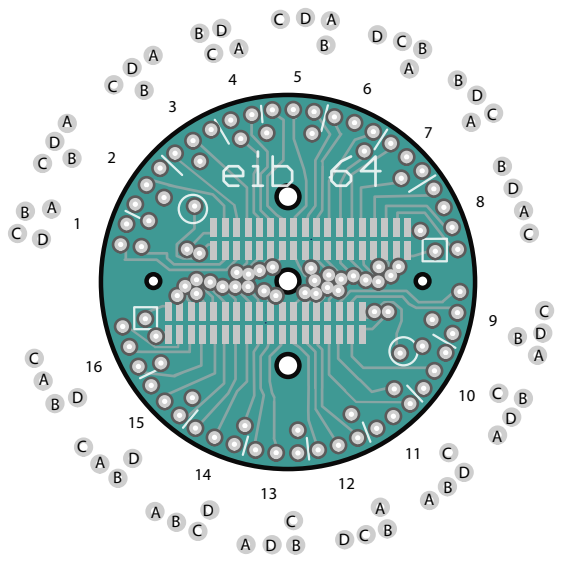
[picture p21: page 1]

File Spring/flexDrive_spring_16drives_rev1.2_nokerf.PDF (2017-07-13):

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

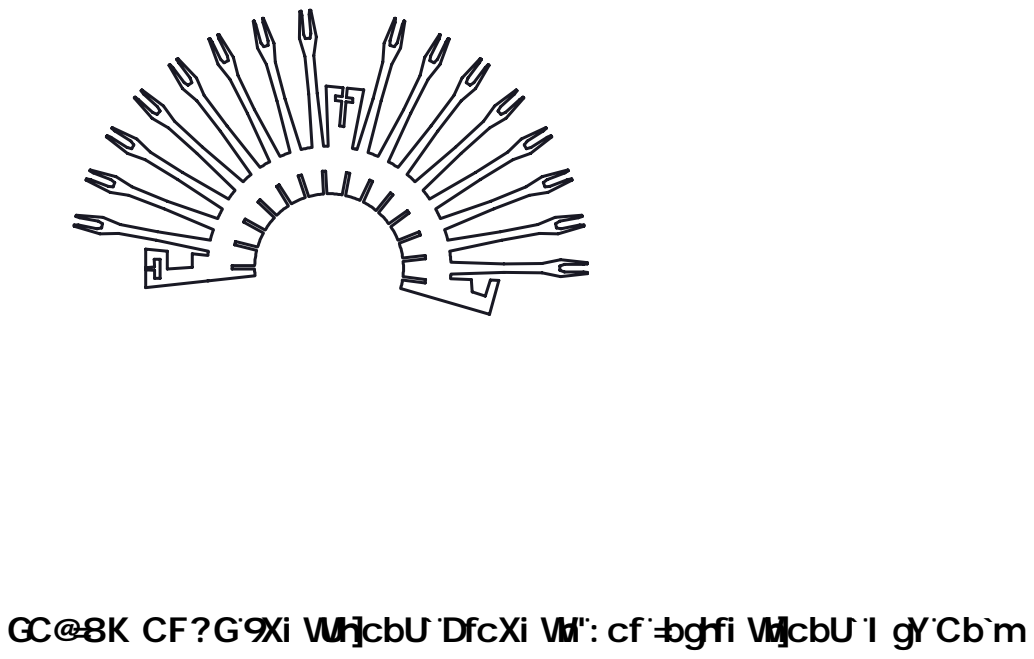
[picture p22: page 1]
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

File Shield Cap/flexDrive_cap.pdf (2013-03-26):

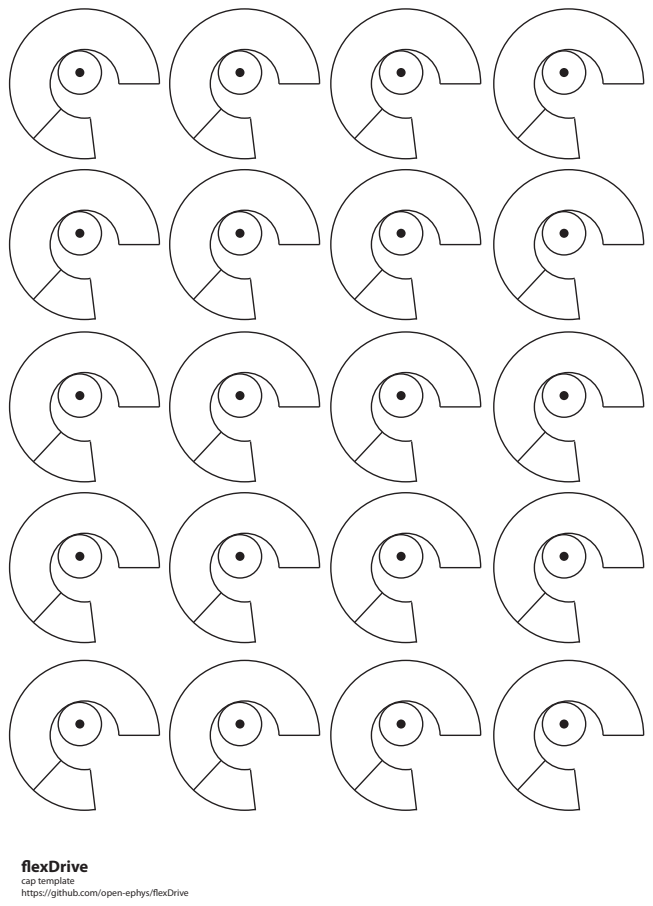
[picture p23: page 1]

exDrive
cap template
https://github.com/open-ephys/exDrive

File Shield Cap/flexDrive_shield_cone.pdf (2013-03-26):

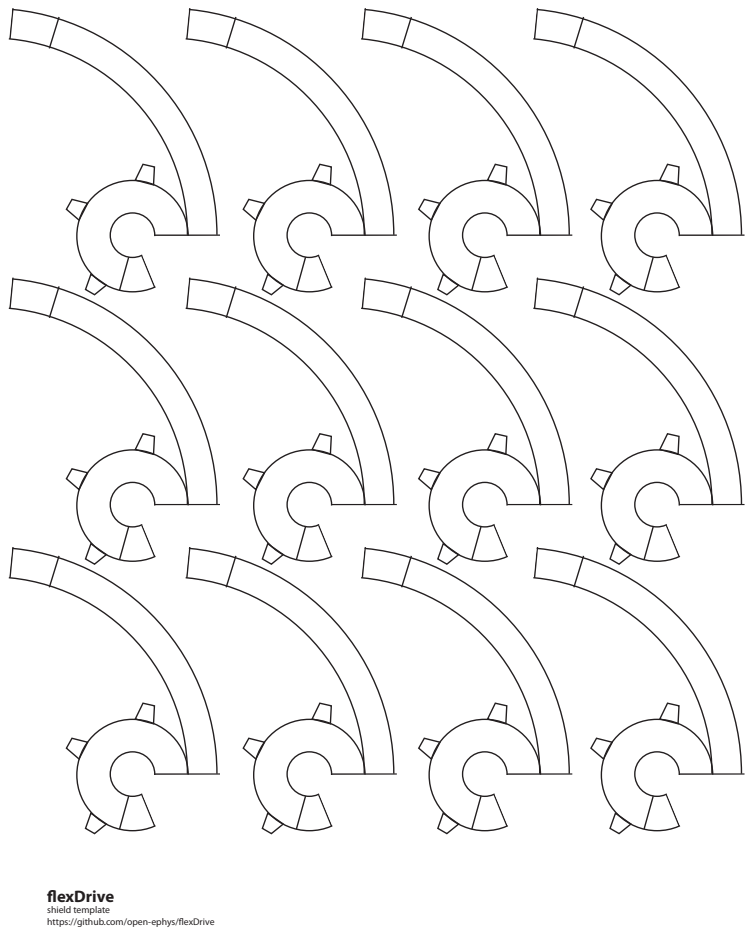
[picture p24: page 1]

exDrive
shield template
https://github.com/open-ephys/exDrive

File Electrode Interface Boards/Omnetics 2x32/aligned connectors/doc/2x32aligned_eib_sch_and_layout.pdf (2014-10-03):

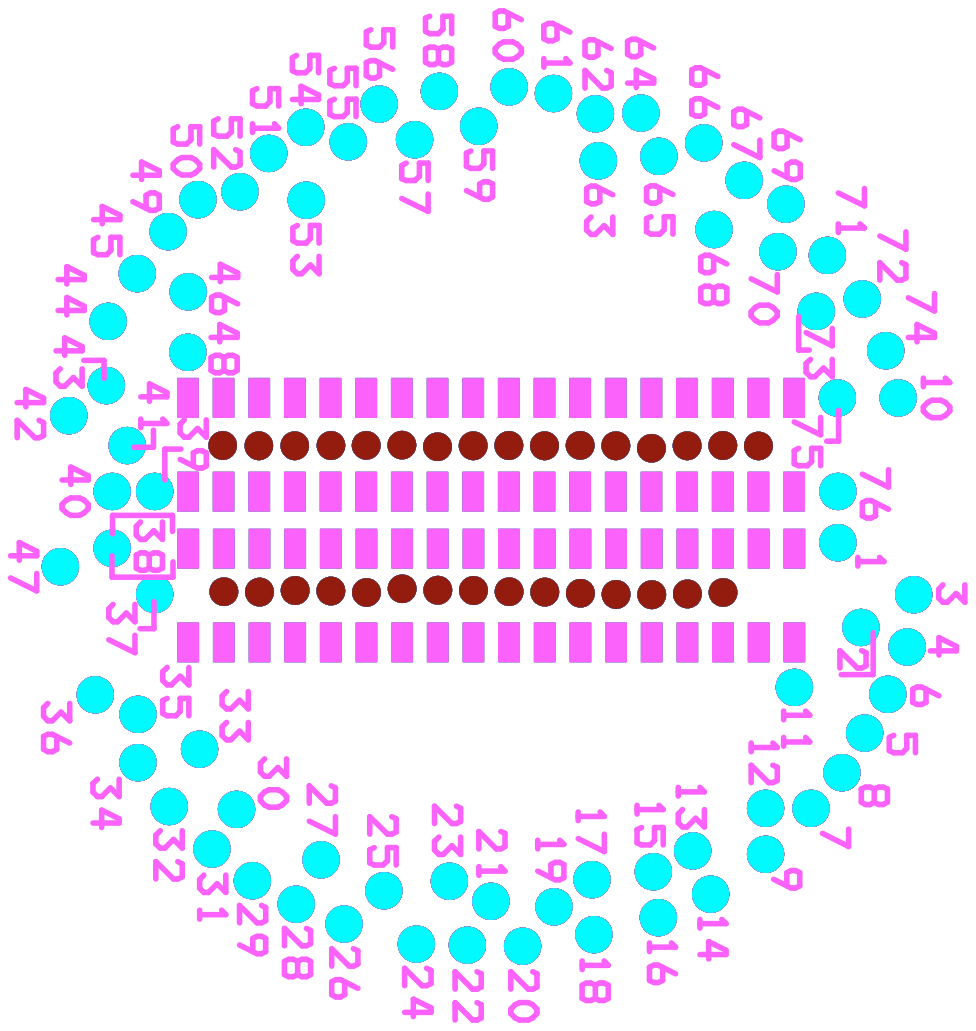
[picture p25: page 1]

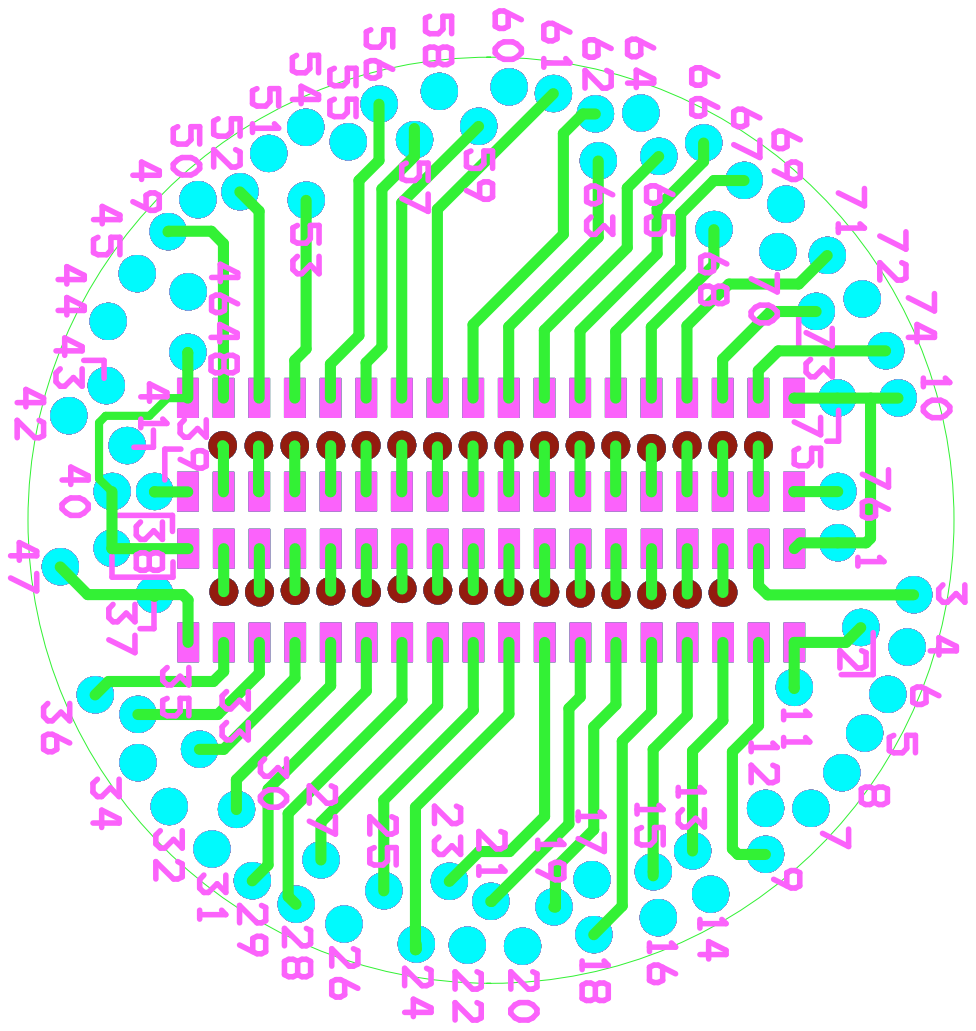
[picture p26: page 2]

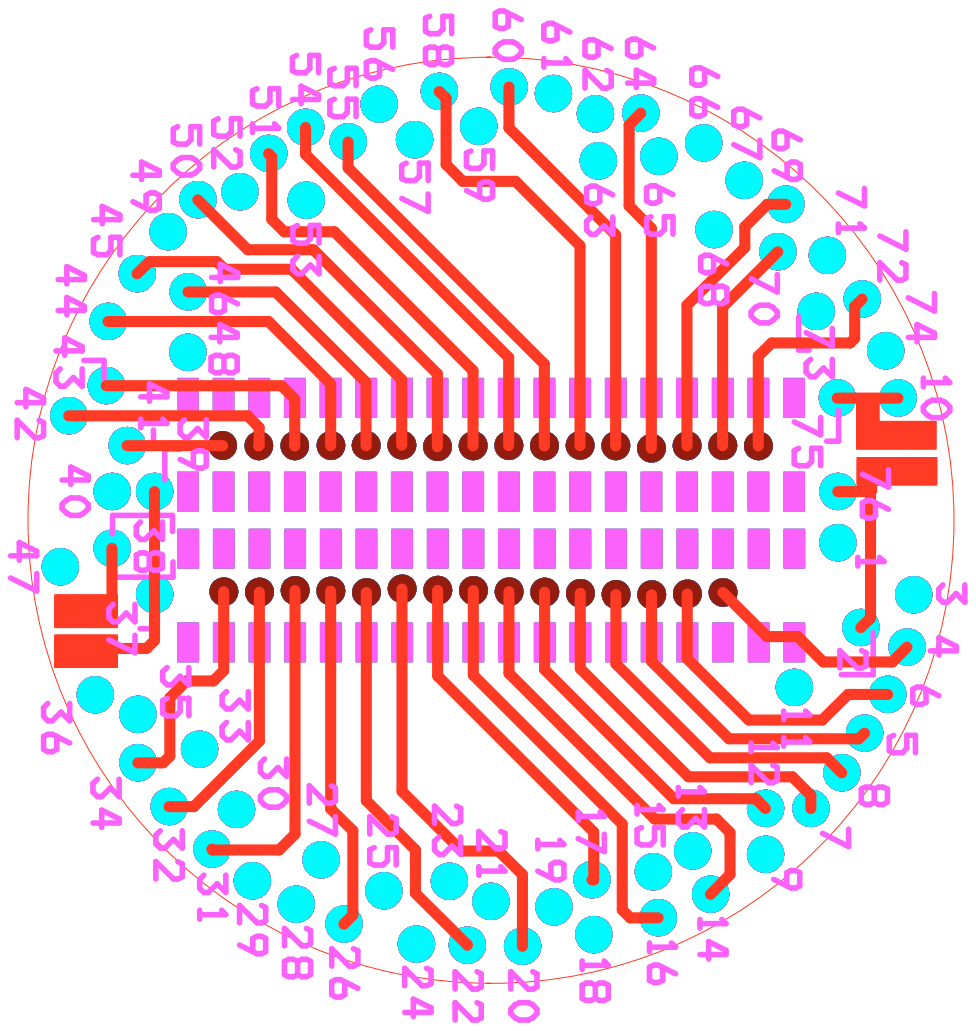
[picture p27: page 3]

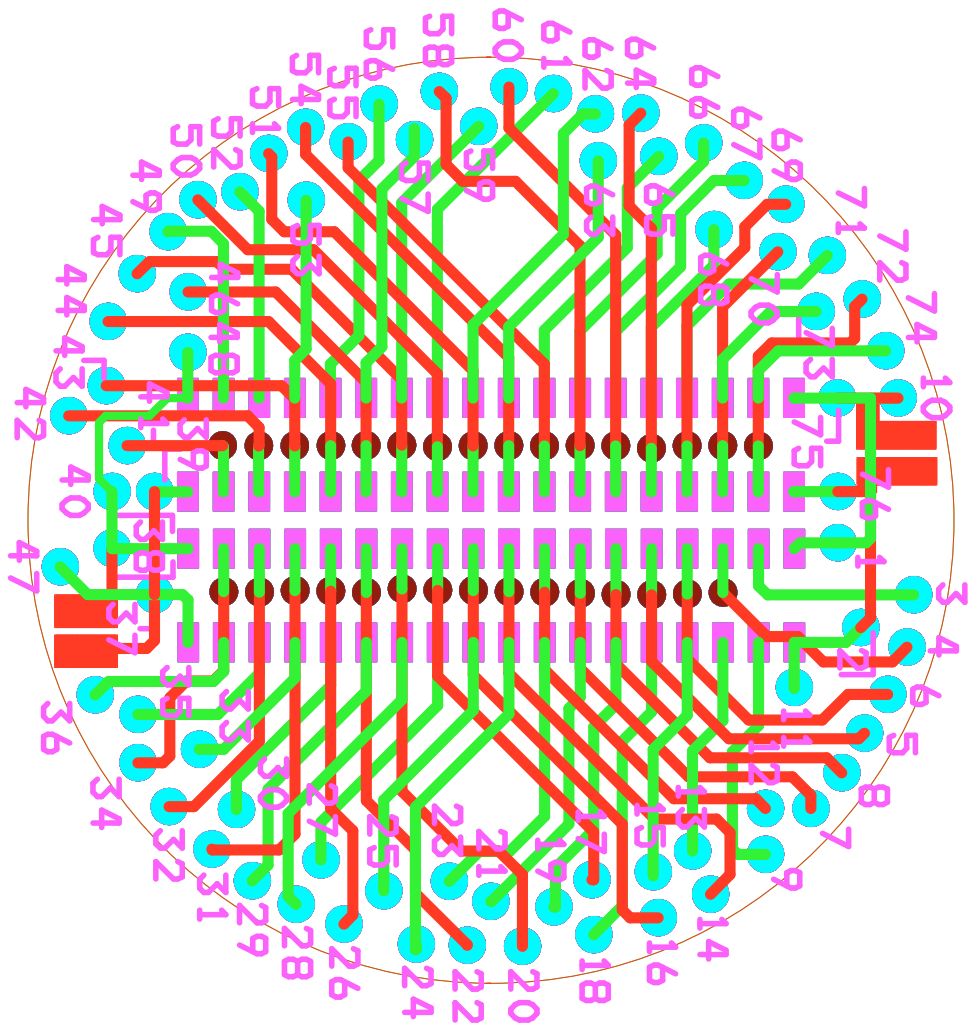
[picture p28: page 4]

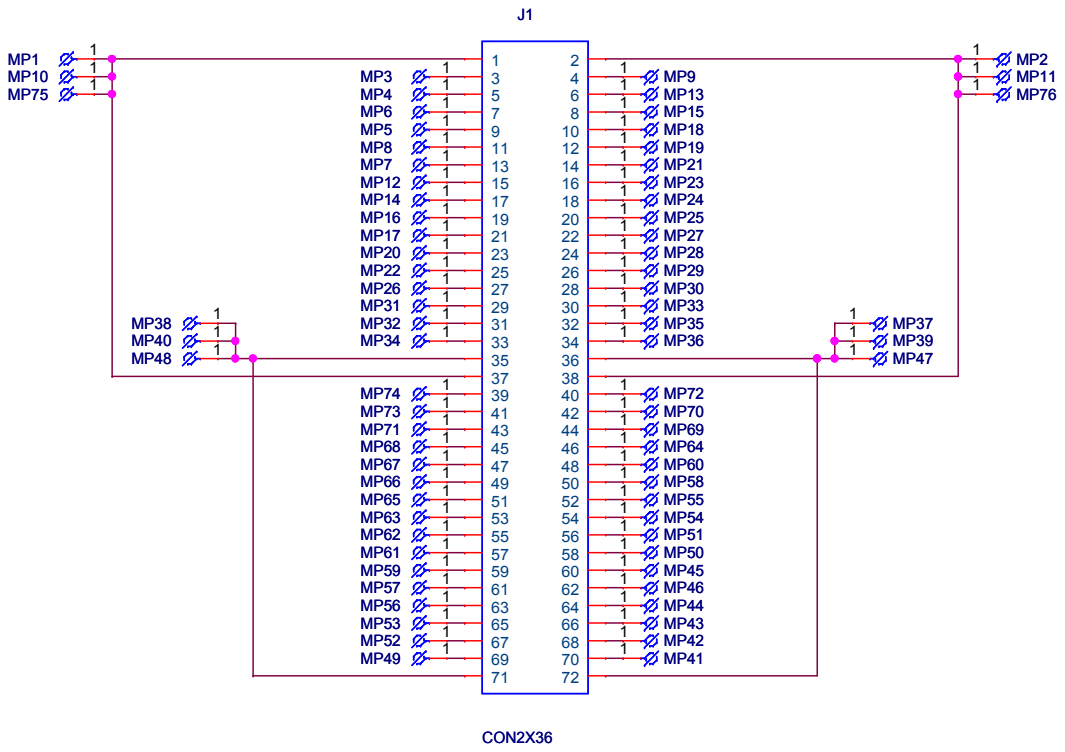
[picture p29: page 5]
Title; Size; Document Number; Rev; Date:; Sheet; Flex drive; . <Title> A4; Monday, July 14, 2014; CON2X36

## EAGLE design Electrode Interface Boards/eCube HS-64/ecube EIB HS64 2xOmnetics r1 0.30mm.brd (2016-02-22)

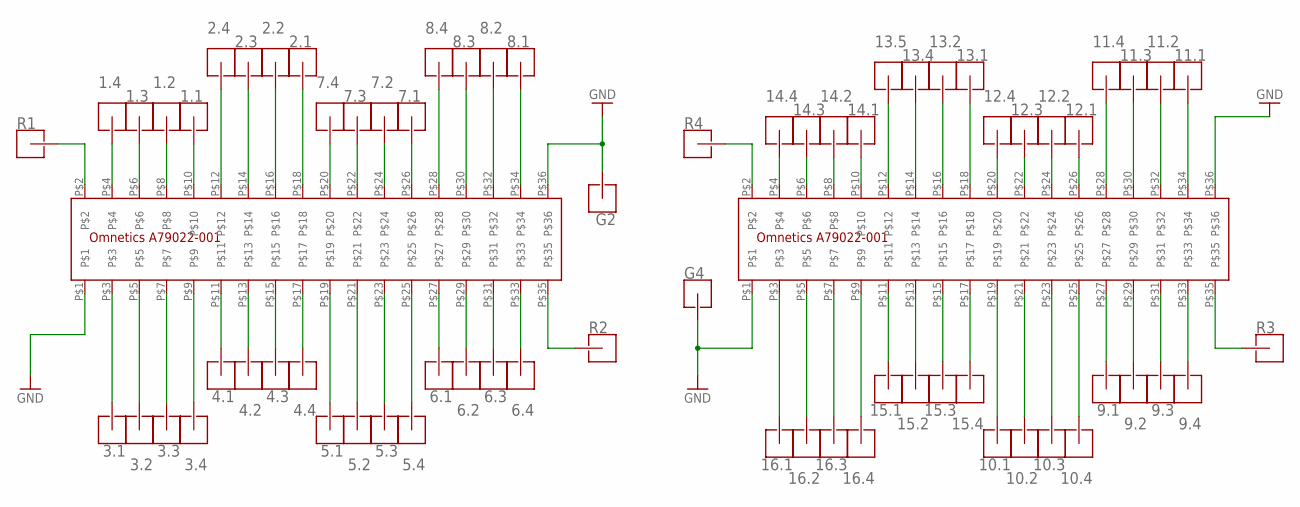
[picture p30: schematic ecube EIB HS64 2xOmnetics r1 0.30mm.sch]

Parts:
1.1, 1.2, 1.3, 1.4, 2.1, 2.2, 2.3, 2.4, 3.1, 3.2, 3.3, 3.4, 4.1, 4.2, 4.3, 4.4, 5.1, 5.2, 5.3, 5.4, 6.1, 6.2, 6.3, 6.4, 7.1, 7.2, 7.3, 7.4, 8.1, 8.2, 8.3, 8.4, 9.1, 9.2, 9.3, 9.4, 10.1, 10.2, 10.3, 10.4, 11.1, 11.2, 11.3, 11.4, 12.1, 12.2, 12.3, 12.4, 13.1, 13.2, 13.4, 13.5, 14.1, 14.2, 14.3, 14.4, 15.1, 15.2, 15.3, 15.4, 16.1, 16.2, 16.3, 16.4: HOLE_S_G_PIN_V3; SMALL_GOLD_PIN_V3
G2, G4: HOLE_L_G_PIN_V1; LARGE_GOLD_PIN_V1
R1, R2, R3, R4: HOLE_L_G_PIN_V1; LARGE_GOLD_PIN_V1
U$1, U$2: A79022-001

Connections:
GND: G2.P$1, G4.P$1, U$1.P$1, U$1.P$36, U$2.P$1, U$2.P$36
unnamed: R4.P$1, U$2.P$2
unnamed: R2.P$1, U$1.P$35
unnamed: R1.P$1, U$1.P$2
unnamed: 14.4.P$1, U$2.P$4
unnamed: 14.3.P$1, U$2.P$6
unnamed: 14.2.P$1, U$2.P$8
unnamed: 14.1.P$1, U$2.P$10
unnamed: 13.5.P$1, U$2.P$12
unnamed: 13.4.P$1, U$2.P$14
unnamed: 13.2.P$1, U$2.P$16
unnamed: 13.1.P$1, U$2.P$18
unnamed: 12.4.P$1, U$2.P$20
unnamed: 12.3.P$1, U$2.P$22
unnamed: 12.2.P$1, U$2.P$24
unnamed: 12.1.P$1, U$2.P$26
unnamed: 11.4.P$1, U$2.P$28
unnamed: 11.3.P$1, U$2.P$30
unnamed: 11.2.P$1, U$2.P$32
unnamed: 11.1.P$1, U$2.P$34
unnamed: 9.4.P$1, U$2.P$33
unnamed: 9.3.P$1, U$2.P$31
unnamed: R3.P$1, U$2.P$35
unnamed: 9.2.P$1, U$2.P$29
unnamed: 9.1.P$1, U$2.P$27
unnamed: 10.4.P$1, U$2.P$25
unnamed: 10.3.P$1, U$2.P$23
unnamed: 10.2.P$1, U$2.P$21
unnamed: 10.1.P$1, U$2.P$19
unnamed: 15.4.P$1, U$2.P$17
unnamed: 15.3.P$1, U$2.P$15
unnamed: 15.2.P$1, U$2.P$13
unnamed: 15.1.P$1, U$2.P$11
unnamed: 3.1.P$1, U$1.P$3
unnamed: 16.4.P$1, U$2.P$9
unnamed: 16.3.P$1, U$2.P$7
unnamed: 3.2.P$1, U$1.P$5
unnamed: 3.3.P$1, U$1.P$7
unnamed: 3.4.P$1, U$1.P$9
unnamed: 4.1.P$1, U$1.P$11
unnamed: 4.2.P$1, U$1.P$13
unnamed: 4.3.P$1, U$1.P$15
unnamed: 4.4.P$1, U$1.P$17
unnamed: 5.1.P$1, U$1.P$19
unnamed: 5.2.P$1, U$1.P$21
unnamed: 5.3.P$1, U$1.P$23
unnamed: 5.4.P$1, U$1.P$25
unnamed: 6.1.P$1, U$1.P$27
unnamed: 6.2.P$1, U$1.P$29
unnamed: 6.3.P$1, U$1.P$31
unnamed: 6.4.P$1, U$1.P$33
unnamed: 16.2.P$1, U$2.P$5
unnamed: 16.1.P$1, U$2.P$3
unnamed: 8.1.P$1, U$1.P$34
unnamed: 8.2.P$1, U$1.P$32
unnamed: 8.3.P$1, U$1.P$30
unnamed: 8.4.P$1, U$1.P$28
unnamed: 7.1.P$1, U$1.P$26
unnamed: 7.2.P$1, U$1.P$24
unnamed: 7.3.P$1, U$1.P$22
unnamed: 7.4.P$1, U$1.P$20
unnamed: 2.1.P$1, U$1.P$18
unnamed: 2.2.P$1, U$1.P$16
unnamed: 2.3.P$1, U$1.P$14
unnamed: 2.4.P$1, U$1.P$12
unnamed: 1.1.P$1, U$1.P$10
unnamed: 1.2.P$1, U$1.P$8
unnamed: 1.3.P$1, U$1.P$6
unnamed: 1.4.P$1, U$1.P$4

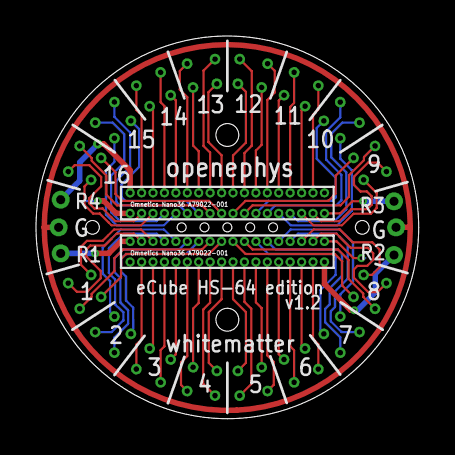
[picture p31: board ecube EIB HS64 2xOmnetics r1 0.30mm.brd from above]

Board: 2 copper layers, 21.3 x 21.3 mm, 72 parts (0 on the bottom side), 69 nets.

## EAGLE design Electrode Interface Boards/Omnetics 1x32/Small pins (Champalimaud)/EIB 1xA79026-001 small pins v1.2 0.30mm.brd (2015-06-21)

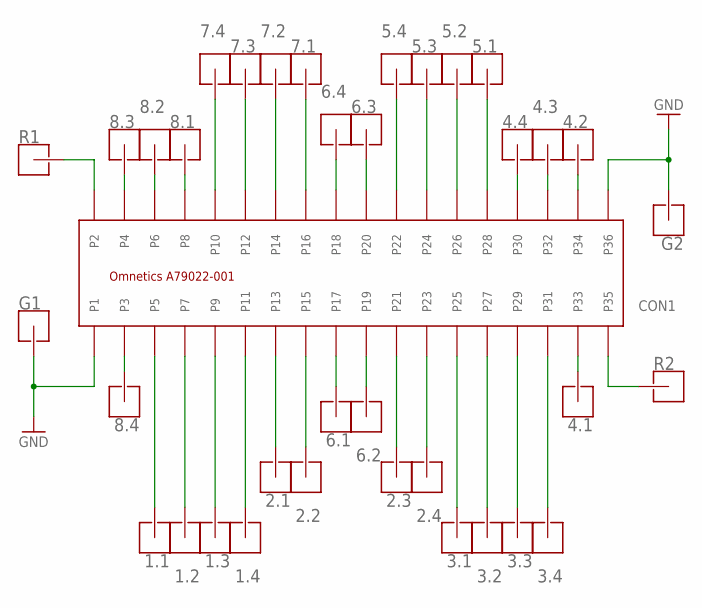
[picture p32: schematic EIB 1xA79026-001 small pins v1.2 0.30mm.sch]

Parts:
1.1, 1.2, 1.3, 1.4, 2.1, 2.2, 2.3, 2.4, 3.1, 3.2, 3.3, 3.4, 4.1, 4.2, 4.3, 4.4, 5.1, 5.2, 5.3, 5.4, 6.1, 6.2, 6.3, 6.4, 7.1, 7.2, 7.3, 7.4, 8.1, 8.2, 8.3, 8.4: HOLE_S_G_PIN_V3; SMALL_GOLD_PIN_V3
CON1: A79022-001_MALESMD; A79026-001_MALE
G1, G2: HOLE_S_G_PIN_V3; SMALL_GOLD_PIN_V3
R1, R2: HOLE_S_G_PIN_V3; SMALL_GOLD_PIN_V3

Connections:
GND: CON1.P1, CON1.P36, G1.P$1, G2.P$1
unnamed: 1.1.P$1, CON1.P5
unnamed: 1.2.P$1, CON1.P7
unnamed: 1.3.P$1, CON1.P9
unnamed: 4.1.P$1, CON1.P33
unnamed: 4.3.P$1, CON1.P32
unnamed: 4.2.P$1, CON1.P34
unnamed: 1.4.P$1, CON1.P11
unnamed: 4.4.P$1, CON1.P30
unnamed: 6.1.P$1, CON1.P17
unnamed: 6.2.P$1, CON1.P19
unnamed: 6.3.P$1, CON1.P20
unnamed: 7.3.P$1, CON1.P12
unnamed: 2.1.P$1, CON1.P13
unnamed: 2.2.P$1, CON1.P15
unnamed: 2.3.P$1, CON1.P21
unnamed: 2.4.P$1, CON1.P23
unnamed: 3.1.P$1, CON1.P25
unnamed: 3.2.P$1, CON1.P27
unnamed: 3.3.P$1, CON1.P29
unnamed: 3.4.P$1, CON1.P31
unnamed: 6.4.P$1, CON1.P18
unnamed: 8.4.P$1, CON1.P3
unnamed: 8.3.P$1, CON1.P4
unnamed: 8.2.P$1, CON1.P6
unnamed: 8.1.P$1, CON1.P8
unnamed: 7.2.P$1, CON1.P14
unnamed: 7.1.P$1, CON1.P16
unnamed: 7.4.P$1, CON1.P10
unnamed: 5.1.P$1, CON1.P28
unnamed: 5.2.P$1, CON1.P26
unnamed: 5.4.P$1, CON1.P22
unnamed: 5.3.P$1, CON1.P24
unnamed: CON1.P2, R1.P$1
unnamed: CON1.P35, R2.P$1

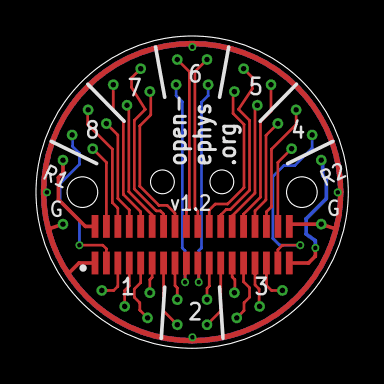
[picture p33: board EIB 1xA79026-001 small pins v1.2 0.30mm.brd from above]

Board: 2 copper layers, 17.3 x 17.3 mm, 37 parts (0 on the bottom side), 35 nets.

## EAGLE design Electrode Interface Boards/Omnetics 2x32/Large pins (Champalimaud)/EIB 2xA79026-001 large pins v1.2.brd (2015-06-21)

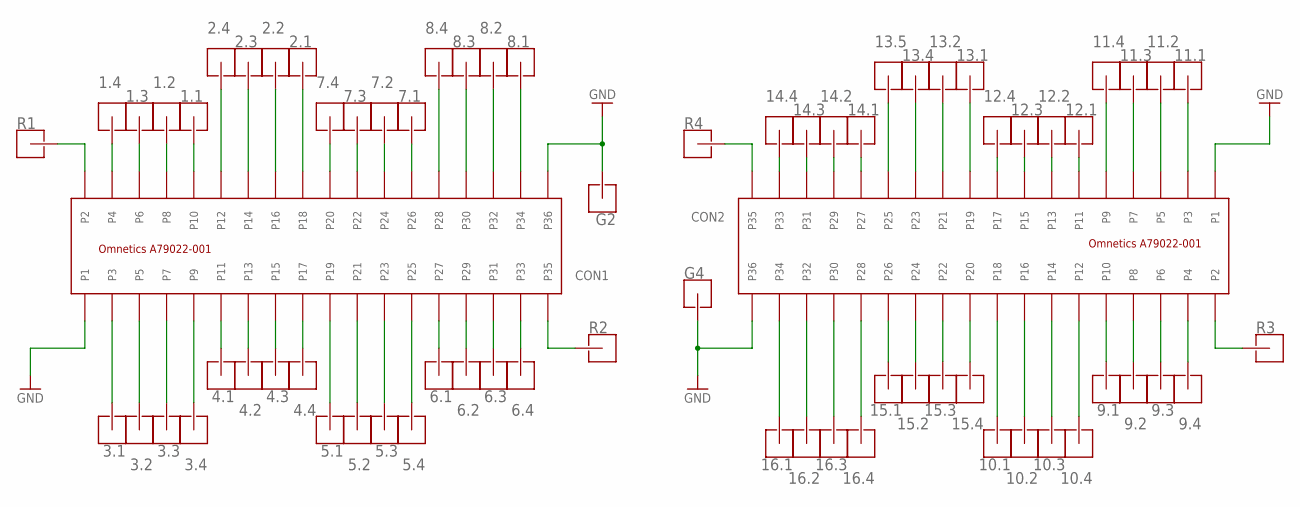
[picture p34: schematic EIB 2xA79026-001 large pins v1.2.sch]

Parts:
1.1, 1.2, 1.3, 1.4, 2.1, 2.2, 2.3, 2.4, 3.1, 3.2, 3.3, 3.4, 4.1, 4.2, 4.3, 4.4, 5.1, 5.2, 5.3, 5.4, 6.1, 6.2, 6.3, 6.4, 7.1, 7.2, 7.3, 7.4, 8.1, 8.2, 8.3, 8.4, 9.1, 9.2, 9.3, 9.4, 10.1, 10.2, 10.3, 10.4, 11.1, 11.2, 11.3, 11.4, 12.1, 12.2, 12.3, 12.4, 13.1, 13.2, 13.4, 13.5, 14.1, 14.2, 14.3, 14.4, 15.1, 15.2, 15.3, 15.4, 16.1, 16.2, 16.3, 16.4: HOLE_L_G_PIN_V5; LARGE_GOLD_PIN_V5
CON1, CON2: A79022-001_MALESMD; A79026-001_MALE
G2, G4: HOLE_L_G_PIN_V5; LARGE_GOLD_PIN_V5
R1, R2, R3, R4: HOLE_L_G_PIN_V5; LARGE_GOLD_PIN_V5

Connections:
GND: CON1.P1, CON1.P36, CON2.P1, CON2.P36, G2.P$1, G4.P$1
unnamed: 11.2.P$1, CON2.P5
unnamed: 11.3.P$1, CON2.P7
unnamed: 11.4.P$1, CON2.P9
unnamed: 14.4.P$1, CON2.P33
unnamed: 16.2.P$1, CON2.P32
unnamed: 16.1.P$1, CON2.P34
unnamed: 12.1.P$1, CON2.P11
unnamed: 16.3.P$1, CON2.P30
unnamed: 12.4.P$1, CON2.P17
unnamed: 13.1.P$1, CON2.P19
unnamed: 15.4.P$1, CON2.P20
unnamed: 10.4.P$1, CON2.P12
unnamed: 12.2.P$1, CON2.P13
unnamed: 12.3.P$1, CON2.P15
unnamed: 13.2.P$1, CON2.P21
unnamed: 13.4.P$1, CON2.P23
unnamed: 13.5.P$1, CON2.P25
unnamed: 14.1.P$1, CON2.P27
unnamed: 14.2.P$1, CON2.P29
unnamed: 14.3.P$1, CON2.P31
unnamed: 10.1.P$1, CON2.P18
unnamed: 11.1.P$1, CON2.P3
unnamed: 9.4.P$1, CON2.P4
unnamed: 9.3.P$1, CON2.P6
unnamed: 9.2.P$1, CON2.P8
unnamed: 10.3.P$1, CON2.P14
unnamed: 10.2.P$1, CON2.P16
unnamed: 9.1.P$1, CON2.P10
unnamed: 16.4.P$1, CON2.P28
unnamed: 15.1.P$1, CON2.P26
unnamed: 15.3.P$1, CON2.P22
unnamed: 15.2.P$1, CON2.P24
unnamed: CON1.P2, R1.P$1
unnamed: CON2.P2, R3.P$1
unnamed: CON2.P35, R4.P$1
unnamed: CON1.P35, R2.P$1
unnamed: 3.2.P$1, CON1.P5
unnamed: 3.3.P$1, CON1.P7
unnamed: 3.4.P$1, CON1.P9
unnamed: 4.1.P$1, CON1.P11
unnamed: 4.2.P$1, CON1.P13
unnamed: 4.3.P$1, CON1.P15
unnamed: 5.2.P$1, CON1.P21
unnamed: 5.3.P$1, CON1.P23
unnamed: 5.4.P$1, CON1.P25
unnamed: 7.4.P$1, CON1.P20
unnamed: 7.3.P$1, CON1.P22
unnamed: 7.2.P$1, CON1.P24
unnamed: 4.4.P$1, CON1.P17
unnamed: 5.1.P$1, CON1.P19
unnamed: 7.1.P$1, CON1.P26
unnamed: 2.1.P$1, CON1.P18
unnamed: 3.1.P$1, CON1.P3
unnamed: 1.4.P$1, CON1.P4
unnamed: 1.3.P$1, CON1.P6
unnamed: 1.2.P$1, CON1.P8
unnamed: 2.4.P$1, CON1.P12
unnamed: 2.3.P$1, CON1.P14
unnamed: 2.2.P$1, CON1.P16
unnamed: 1.1.P$1, CON1.P10
unnamed: 6.4.P$1, CON1.P33
unnamed: 6.1.P$1, CON1.P27
unnamed: 6.2.P$1, CON1.P29
unnamed: 6.3.P$1, CON1.P31
unnamed: 8.1.P$1, CON1.P34
unnamed: 8.2.P$1, CON1.P32
unnamed: 8.3.P$1, CON1.P30
unnamed: 8.4.P$1, CON1.P28

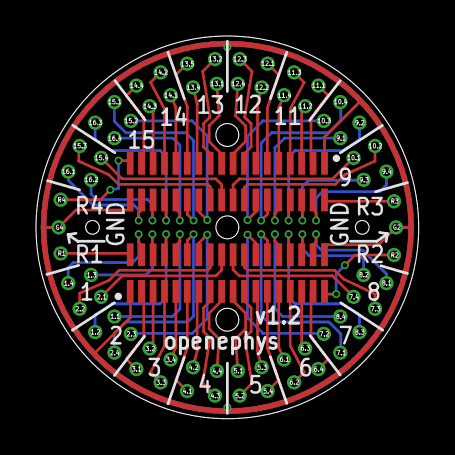
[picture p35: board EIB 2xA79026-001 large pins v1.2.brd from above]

Board: 2 copper layers, 21.3 x 21.3 mm, 72 parts (0 on the bottom side), 69 nets.

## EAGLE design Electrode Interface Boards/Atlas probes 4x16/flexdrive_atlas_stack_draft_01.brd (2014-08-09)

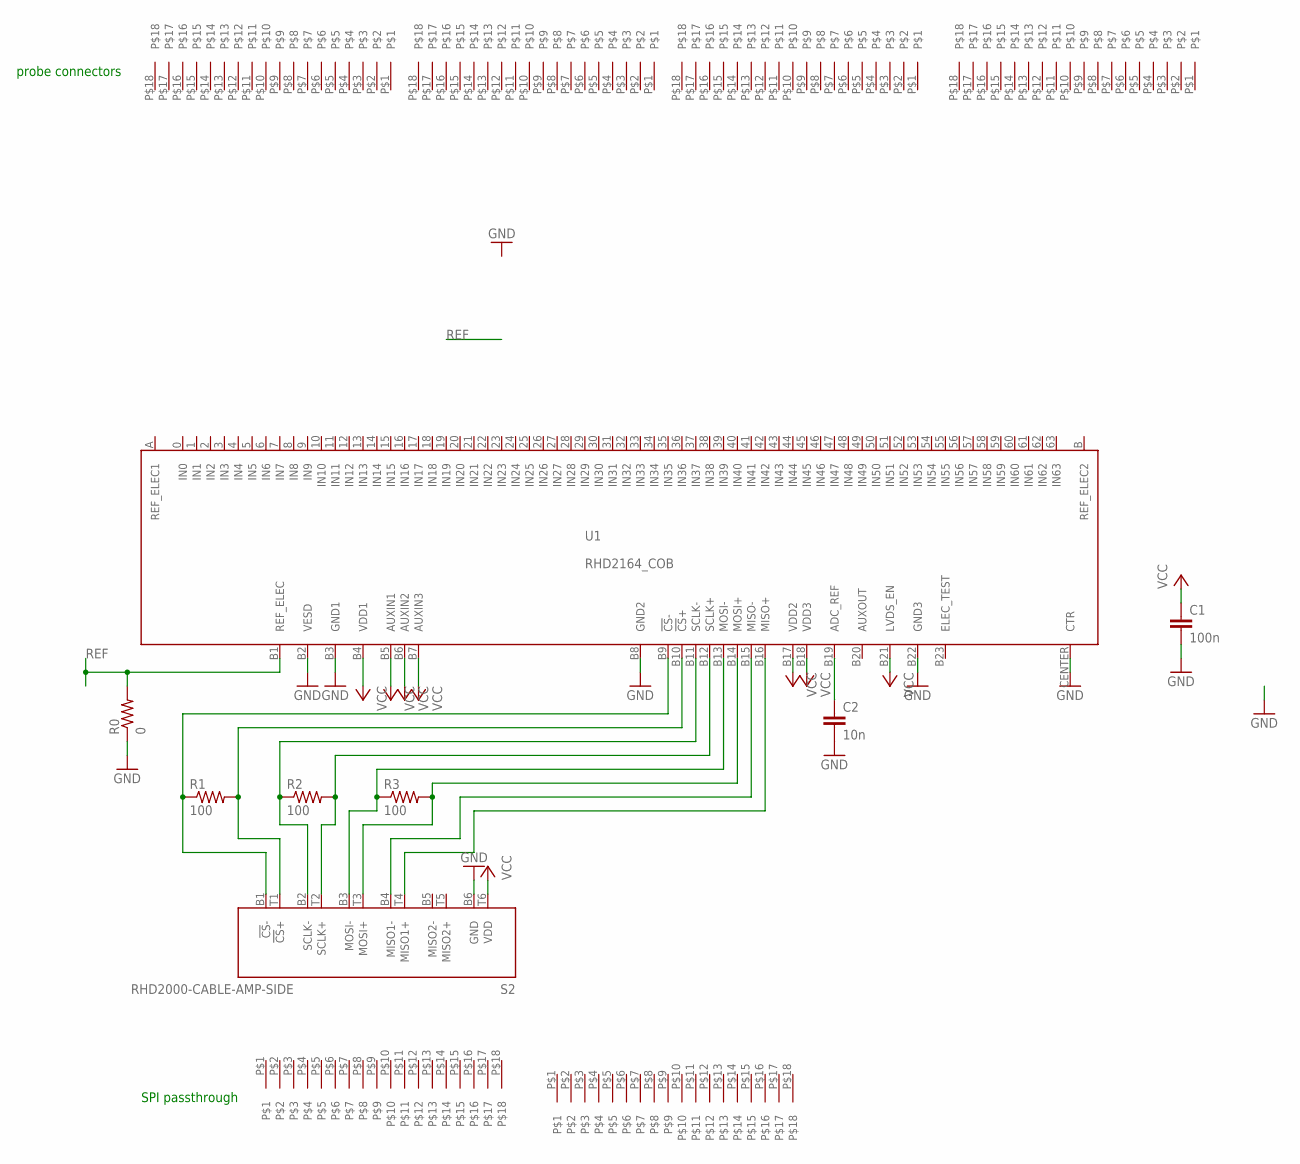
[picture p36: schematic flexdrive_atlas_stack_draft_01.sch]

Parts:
C1: 100n; 0402
C2: 10n; 0201
R0: 0; 0402
R1, R2, R3: 100; 0201
S2: RHD2000-CABLE-AMP-SIDE; OMNETICS_PZN-12-AA
U1: RHD2164_COB
U$1, U$2, U$3, U$4, U$5, U$6: 18PIN_035MM_SLIMSTACK; 18PIN_025MM_SLIMSTACK

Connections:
GND: C1.2, C2.2, R0.1, S2.B6 (GND), U1.B2 (VESD), U1.B3 (GND1), U1.B8 (GND2), U1.B22 (GND3), U1.CENTER (CTR)
unnamed: S2.T4 (MISO1+), U1.B16 (MISO+)
unnamed: R1.1, S2.B1 (!CS!-), U1.B9 (!CS!-)
unnamed: R1.2, S2.T1 (!CS!+), U1.B10 (!CS!+)
unnamed: R2.1, S2.B2 (SCLK-), U1.B11 (SCLK-)
unnamed: R2.2, S2.T2 (SCLK+), U1.B12 (SCLK+)
unnamed: R3.1, S2.B3 (MOSI-), U1.B13 (MOSI-)
unnamed: R3.2, S2.T3 (MOSI+), U1.B14 (MOSI+)
unnamed: S2.B4 (MISO1-), U1.B15 (MISO-)
unnamed: C2.1, U1.B19 (ADC_REF)
REF: R0.2, U1.B1 (REF_ELEC)
VCC: C1.1, S2.T6 (VDD), U1.B4 (VDD1), U1.B5 (AUXIN1), U1.B6 (AUXIN2), U1.B7 (AUXIN3), U1.B17 (VDD2), U1.B18 (VDD3), U1.B21 (LVDS_EN)

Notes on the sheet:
SPI passthrough
probe connectors

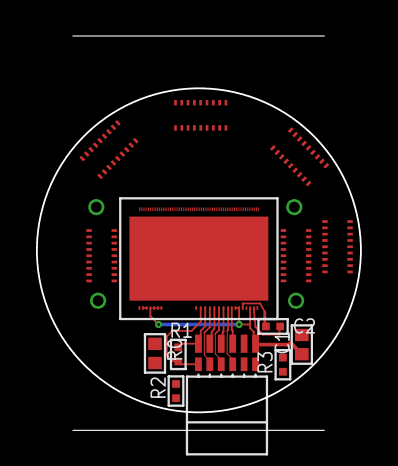
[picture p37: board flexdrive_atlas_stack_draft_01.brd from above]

Board: 2 copper layers, 18.0 x 18.0 mm, 14 parts (0 on the bottom side), 12 nets.

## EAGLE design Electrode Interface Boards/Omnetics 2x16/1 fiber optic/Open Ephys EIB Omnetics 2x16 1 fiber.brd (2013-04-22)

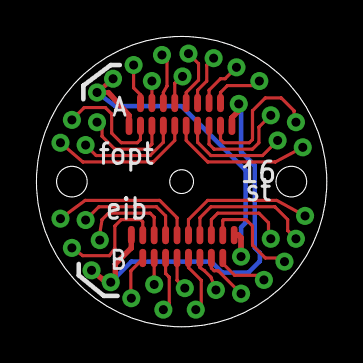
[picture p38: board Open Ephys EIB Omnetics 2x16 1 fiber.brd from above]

Board: 2 copper layers, 16.1 x 16.1 mm, 40 parts (0 on the bottom side), 34 nets.

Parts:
U$1, U$2: OMNETICS_FE18
U$3, U$4, U$5, U$6, U$7, U$8, U$9, U$10, U$11, U$12, U$13, U$14, U$15, U$16, U$17, U$18, U$19, U$20, U$21, U$22, U$23, U$24, U$25, U$26, U$27, U$28, U$29, U$30, U$31, U$32, U$33, U$34, U$35, U$36, U$37, U$38, U$39, U$40: GOLDPINLARGE; LARGEGOLDPIN

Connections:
unnamed: U$2.P$15, U$28.P1
unnamed: U$2.P$14, U$29.P1
unnamed: U$1.P$8, U$3.P1
unnamed: U$1.P$7, U$5.P1
unnamed: U$1.P$6, U$4.P1
unnamed: U$1.P$5, U$6.P1
unnamed: U$1.P$4, U$7.P1
unnamed: U$1.P$3, U$8.P1
unnamed: U$1.P$2, U$9.P1
unnamed: U$1.P$1, U$10.P1
unnamed: U$1.P$16, U$18.P1
unnamed: U$1.P$15, U$17.P1
unnamed: U$1.P$14, U$16.P1
unnamed: U$1.P$13, U$15.P1
unnamed: U$1.P$12, U$14.P1
unnamed: U$1.P$11, U$13.P1
unnamed: U$1.P$10, U$12.P1
unnamed: U$1.P$9, U$11.P1
unnamed: U$2.P$1, U$26.P1
unnamed: U$2.P$2, U$25.P1
unnamed: U$2.P$3, U$24.P1
unnamed: U$2.P$4, U$23.P1
unnamed: U$2.P$5, U$22.P1
unnamed: U$2.P$6, U$21.P1
unnamed: U$2.P$7, U$20.P1
unnamed: U$2.P$8, U$19.P1
unnamed: U$2.P$9, U$36.P1
unnamed: U$2.P$10, U$35.P1
unnamed: U$2.P$11, U$34.P1
unnamed: U$2.P$12, U$33.P1
unnamed: U$2.P$13, U$32.P1
unnamed: U$2.P$16, U$27.P1
unnamed: U$1.P$17, U$2.P$17, U$31.P1, U$39.P1, U$40.P1
REF1: U$1.P$18, U$2.P$18, U$30.P1, U$37.P1, U$38.P1

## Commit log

2013-03-14 initial commit 64 channel flexdrive EIB
    added brd file and gerber files for first production run
    [64ch_eib_omnetics_3fibers.brd]
2013-03-14 initial commit 32 channel flexdrive EIBs
    added brd files for two variants of the 32ch eib, for one and two fibers
    [32ch_eib_omnetics_1fiber.brd, 32ch_eib_omnetics_2fibers.brd]
2013-03-26 initial commit drive spring files
    [flexDrive_spring_16drives_rev1.0.SLDDRW, flexDrive_spring_16drives_rev1.0.SLDPRT, flexDrive_spring_16drives_rev1.0_wireedm_dfx_inch.DXF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]
2013-03-26 initial commit flexDrive body source files
    [flexDrive_base_16drives_rev1.0.SLDPRT, flexDrive_base_16drives_rev1.1.SLDDRW, flexDrive_base_16drives_rev1.1.SLDPRT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]
2013-03-26 added bilateral hippocampus implant body
    [flexDrive_ca1_bilateral_16drives_rev1.1.SLDPRT]
2013-03-26 fixed drc errors
    changed mounting holes to 0.762mm
    moved some electrode pin vias away from edge
    re-routed central traces around ferrule hole
    [64ch_eib_omnetics_3fibers.brd]
2013-04-02 fixed 5mil spacing drc error
    changed some vias to 0.008" to make more space for the routing between
    the omnetics connectors
    [64ch_eib_omnetics_3fibers.brd]
2013-04-03 added 32ch eib variant with 3 ferrule holes
    requires 5mil traces
    [32ch_eib_omnetics_3fibers.brd]
2013-04-12 added solidworks file for spring without kerf
    kerf is not accounted for in this part
    There are areas where a 13mil kerf will not be able to follow the
    outlines, such as the cutout where the screw will fit - it is probably
    ok to just not cut as deep of a cutout there.
    [flexDrive_spring_16drives_nokerf_rev1.0.SLDPRT]
2013-04-14 Remove 32ch + 64ch EIB folders
    [32ch_eib_omnetics_1fiber.brd, 32ch_eib_omnetics_2fibers.brd, 32ch_eib_omnetics_3fibers.brd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]
2013-04-14 Add new EIB directories
    [Open Ephys EIB Omnetics 1x32 2 fibers.brd, Open Ephys EIB Omnetics 2x16 1 fiber.brd, Open Ephys EIB Omnetics 2x16 2 fibers.brd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]
2013-04-14 Rename README files
    [Open Ephys EIB Omnetics 1x32 2 fibers.brd]
2013-04-15 Add Gerber files for 1x32 EIB
    [Open Ephys EIB Omnetics 1x32 2 fibers.brd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]
2013-04-15 Add Gerber files and images for EIBs
    [Open Ephys EIB Omnetics 2x16 1 fiber.brd, Open Ephys EIB Omnetics 2x16 2 fibers.brd, Open Ephys EIB Omnetics 2x16 3 fibers.brd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]
2013-04-22 Fix spacing issues on 2x16 boards
    [Open Ephys EIB Omnetics 2x16 1 fiber.brd, Open Ephys EIB Omnetics 2x16 2 fibers.brd, Open Ephys EIB Omnetics 2x16 3 fibers.brd]
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2013-04-23 Fix unconnected trace on 1x32 EIB
    [Open Ephys EIB Omnetics 1x32 2 fibers.brd]
2013-05-02 add CA1 bilateral STL
    [flexDrive_ca1_bilateral_16drives_rev1.1.SLDPRT, flexDrive_ca1_bilateral_16drives_rev1.1.STL]
2013-05-02 added dxf file for spring with no kerf adjustment
    [flexDrive_spring_16drives_nokerf_rev1.0_wireedm_dfx_inch.DXF]
2013-05-02 added printout sheet for 64ch EIB
2013-05-07 Update design for bilateral drive
    [Open Ephys EIB Omnetics 1x32 2 fibers.brd, flexDrive_ca1_bilateral_16drives_rev1.1.SLDPRT, flexDrive_ca1_bilateral_16drives_rev1.1.STL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]
2013-05-21 moved mounting holes to fix spacing violation
    [Open Ephys EIB Omnetics 2x32 3 fibers.brd]
2013-05-21 updated gerber files
    [Open Ephys EIB Omnetics 2x32 3 fibers.brd]
2013-05-25 IGS and STEP files for bilateral CA1 drive
    committing new files in josh's design
    [flexDrive_ca1_bilateral_16drives_rev1.1.STEP]
2013-05-28 Fixed spacing issue
    [Open Ephys EIB Omnetics 2x32 3 fibers.brd]
2013-08-07 Made kerf adjusted new rev
    smaller heads no hooks, for 13mil kerf
    should be functionally similar to the not kerf adjusted version
    [flexDrive_spring_16drives_rev1.1.SLDPRT, flexDrive_spring_16drives_rev1.1_wireedm_dfx_inch.DXF]
2013-11-05 Add Gerber files for 1x32 design
2013-11-07 Add Eagle and AI files for 2x32 large gold pin version
    [Open Ephys EIB Omnetics 2x32 3 fibers large gold pins.brd]
2013-12-03 Reorganized 2x32eib to large and small pin folders
    [Open Ephys EIB Omnetics 2x32 3 fibers large gold pins.brd, Open Ephys EIB Omnetics 2x32 3 fibers.brd]
2014-02-06 Add drive base for 64-channel large EIBs
    [flexDrive_base_16drives_rev1.1.STEP, flexDrive_ca1_bilateral_16drives_rev1.2.SLDPRT, flexDrive_ca1_bilateral_16drives_rev1.2.STL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]
2014-02-11 organized into folders for small/large EIBs
    [flexDrive_base_16drives_rev1.0.SLDPRT, flexDrive_base_16drives_rev1.1.SLDDRW, flexDrive_base_16drives_rev1.1.SLDPRT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]
2014-02-12 added PCB spec warning and updated links
2014-06-22 Initial commit This is a _very_ rough draft to test the fit of 4 16ch connectors for laminar probe flex cables. There's also 2 connectors for stacking 2 of these EIBs with MISO passthrough. The pass-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
    [flexdrive_atlas_stack_draft_01.brd, flexdrive_atlas_stack_draft_01.sch]
2014-08-09 Update Sunstone gerber files
2014-10-01 Reorganized folders for 64ch headstages
    [Open Ephys EIB Omnetics 2x32 3 fibers large gold pins.brd, Open Ephys EIB Omnetics 2x32 3 fibers.brd]
2014-10-02 Updated spring design
    no big changes, mostly cleared up names and added some length to fork
    tips
    [flexDrive_spring_16drives_rev1.1.SLDPRT, flexDrive_spring_16drives_rev1.1_for_13mil_kerf.DXF, flexDrive_spring_16drives_rev1.1_for_13mil_kerf.SLDPRT]
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2014-10-22 Small revisions to spring
    Heads came out a bit short on 13mil kerf EDM, made them a tad longer.
    [flexDrive_spring_16drives_rev1.2_for_13mil_kerf.DXF, flexDrive_spring_16drives_rev1.2_for_13mil_kerf.SLDPRT]
2014-12-16 re-created Omnetics 1x32 gerbers
    were missing drill files
2015-06-21 Add Champalimaud EIB designs
    [EIB 1xA79026-001 large pins v1.2.brd, EIB 1xA79026-001 large pins v1.2.sch, EIB 1xA79026-001 small pins v1.2 0.30mm.brd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]
2016-02-22 Add EIB designs for eCube headstage
    [ecube EIB HS64 2xOmnetics r1 0.30mm.brd, ecube EIB HS64 2xOmnetics r1 0.30mm.sch]
2016-04-16 Added Gerber files for Champalimaud designs
2016-08-29 added spring design with no baked-in kerf adjustments
    [flexDrive_spring_16drives_rev1.2_nokerf.SLDPRT]
2016-08-29 added spring in DXF,IGS and STEP formats
    [flexDrive_spring_16drives_rev1.2_nokerf.DXF, flexDrive_spring_16drives_rev1.2_nokerf.IGS, flexDrive_spring_16drives_rev1.2_nokerf.STEP]
2017-07-13 added spring in more formats
    [flexDrive_base_16drives_rev1.1.SLDPRT, flexDrive_spring_16drives_rev1.2_nokerf.DWG, flexDrive_spring_16drives_rev1.2_nokerf.DXF]
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
